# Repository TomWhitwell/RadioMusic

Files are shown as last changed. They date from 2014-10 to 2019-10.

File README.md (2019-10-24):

## Radio Music



### A virtual radio module for Eurorack
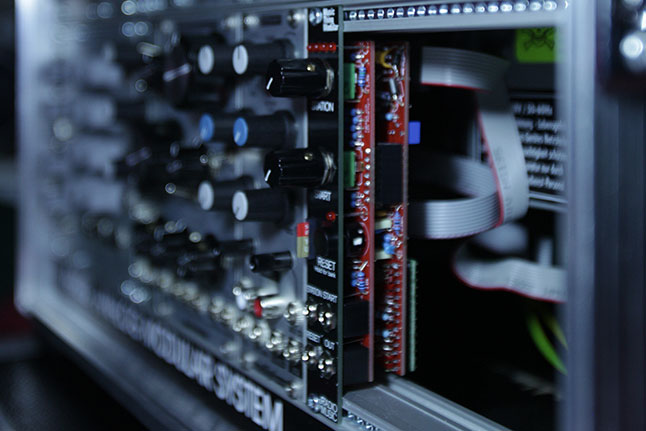
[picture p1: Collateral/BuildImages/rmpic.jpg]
Image from matcsat, Muffwiggler forum


- [Full Documentation](https://github.com/TomWhitwell/RadioMusic/wiki)
    - [Module manual](https://github.com/TomWhitwell/RadioMusic/wiki/How-to-use-the-Radio-Music-module)  
    - [Build documents](https://github.com/TomWhitwell/RadioMusic/wiki/Building-the-Radio-Music-module)  
    - [Setting up the SD Card](https://github.com/TomWhitwell/RadioMusic/wiki/SD-Card%3A-Format-%26-File-Structure)  
    - [Suggested sound library](https://github.com/TomWhitwell/RadioMusic/wiki/Audio-for-the-SD-Card)  
- [Hardware: Eagle CAD files](https://github.com/TomWhitwell/RadioMusic/tree/master/RadioMusicHardware)
- [Hardware: Parts List](https://github.com/TomWhitwell/RadioMusic/wiki/BOM---Parts-List)
- [Firmware: Teensyduino files](https://github.com/TomWhitwell/RadioMusic/tree/master/RadioMusic)
- [Report Issues with hardware or firmware](https://github.com/TomWhitwell/RadioMusic/issues)

This is not a radio. It is a sample player that behaves like a radio.  

A digital way to simulate the radio-powered compositions of John Cage and Karlheinz Stockhausen as well as Don Buchla's voltage-controlled radio experiments. It uses a [Teensy 3.1/3.2](https://www.pjrc.com/teensy/) to play files from an SD card to simulate a voltage controlled AM/FM/Shortwave/Time Travel radio. 

#### Progress  

May 2016
- Merged Jouni's latest changes into the main branch
- New Beta versions in the Collateral/Hex Files folder: Crossfade and a new Bank Change interface
- If you're developing firmware yourself, make sure you read the 'Edited Teensy Files' section, because this has changed significantly

March 2016  
- Updated firmware Beta produced by Jouni Stenroos, fixing several long-term issues including file count limit, hot swapping and resets.  

February 2015  
- [Thonk kits shipping](http://www.thonk.co.uk/product-category/music-thing-modular/)  
- Module being used by:  
    - [Robin Rimbaud (Scanner)](https://twitter.com/robinrimbaud/status/562663428830289921)   
    - [Chris Carter](https://twitter.com/chris_carter_/status/562889299621076993)  
    - [Russell Haswell](https://twitter.com/russellhaswell/status/552213743363690496)  
    - [Richard Devine](https://instagram.com/p/900BnMjQjw/)  
- [Big collection of video and audio demos](http://musicthing.co.uk/modular/?p=1087)  

January 2015  
- Rev2 PCB Files confirmed good  

December 2014  
- [Rev2 PCB files](https://github.com/TomWhitwell/RadioMusic/tree/master/RadioMusicHardware/Gerbers/Rev%202%20Gerbers%20Dec%202014) published, prototyping in process  

November 2014  
- First PCB build   
- [Video 1](http://instagram.com/p/vCNc37DmSj/)  
- [Video 2](http://instagram.com/p/vnv1T-DmUm/)  
- [Longer demo video](http://vimeo.com/113050279)  
- [Audio: Long demo](https://soundcloud.com/musicthing/radio-music-20-minutes-of-madness)  
- [Audio: Random Drums](https://soundcloud.com/musicthing/radio-music-random-drums)  
- [Audio: Random Voices](https://soundcloud.com/musicthing/radio-music-random-voices)   

October 2014   
- Very early prototyping     

#### Features
- 4hp x 40mm deep  
- On-board 5v regulator, does not need a 5v rail.
- 75ma Current Draw   
    - 60ma from 5v regulator  
    - 8ma from -12v  
- Up to 32gb storage, 16 banks of 75 channels each  
- Files stored as headerless .raw wav files
- Customise the module by editing settings.txt on the SD Card

EarlyPanelDesign

#### License  
Radio Music is Open Hardware  
All hardware and software design in this project is Creative Commons licensed by Tom Whitwell: [CC-BY-SA: Attribution / ShareAlike](https://creativecommons.org/licenses/by-sa/3.0/)  
If you use any work in this project, you should credit me, and you must republish any changes you make under the same license.   
This license does permit commercial use of these designs, but consider getting in touch before selling anything.  
This project includes work from the [Teensy](https://www.pjrc.com/teensy/) project, which is not covered by this license. The suggested audio content is not covered by this license.

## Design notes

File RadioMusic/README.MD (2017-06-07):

Radio Music New Firmware

Extra files are no longer needed

To build this firmware and upload to your Radio Music

1. Install Arduino IDE : https://www.arduino.cc/en/Main/Software
2. Install Teensyduino : https://www.pjrc.com/teensy/td_download.html
3. Get a copy of the source code : https://github.com/Normalised/RadioMusic/archive/master.zip
4. Unzip the source code somewhere
5. Connect the Radio Music to your computer via USB. If you are on OSX or Win 10 you won't need drivers.
5. Open RadioMusic.ino in Arduino IDE
6. Click the upload button : Upload

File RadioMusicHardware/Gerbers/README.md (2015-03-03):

#Gerber File Changelog  

##Rev 2.1  
- This folder only includes Front board files. Back and panel boards unchanged from Rev 2   
- Rev 2.1 Changes   
    - Bigger holes for reset button  
    - Correct revision number on silkscreen (!)  

##Rev 2 
- Boards used for first major production run in January 2015  

##Rev 1 
- Prototype boards with ground error on front board. Do not use. 

##NB These Gerbers may not reflect the latest Eagle updates. For latest version, create your own Gerbers from the eagle files.

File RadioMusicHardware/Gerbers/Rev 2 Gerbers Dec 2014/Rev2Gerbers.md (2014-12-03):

##Rev 2 Gerbers  

These gerbers are prepared to Seeed Studio specs   

Things to check  
- The panel PCB includes a cutout for the SD card - this is marked in the Outline layer (.OUT), and also in the milling layer (.GML)   
- On the panel, ask your PCB house not to put their serial number on top silkscreen (the front of the panel)  

The Eagle archive is here as a snapshot of the Eagle files these PCBs were made from. The main eagle files in the repository are constantly updating

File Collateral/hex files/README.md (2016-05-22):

##Hex File Changelog  
23-3-2016: Rev 2.0 BETA (jstenroos)
    - Fixed hotswap
    - Removed file number limit of ~330. Full 1200 files (16 banks of 75 files each) is now possible.
    - Fine tuned reset. Works properly now after channel change. Also can be set to beginning of the file properly.
    - Added optional alphabetical sort for banks.

27-3-2016: RadioMusic_Beta_2.hex
- Code refactored by Jouni Stenroos  
    - Fixed hotswap, file limit, reset and added sort  
    - [Details here](https://www.muffwiggler.com/forum/viewtopic.php?p=2184098#2184098)  
    - Currently being developed [in this branch](https://github.com/jstenroos/RadioMusic/tree/dev_200).
    - [Direct link to the hex file here](https://raw.githubusercontent.com/TomWhitwell/RadioMusic/master/Collateral/hex%20files/Beta/RadioMusic_Beta_2.hex). Save from the browser and rename .txt into .hex  
    
1-3-2016: RM_Beta_Delay.hex  
- As Rev1.1 with longer startup delay as suggested by mxmxmx to fix startup issues seen by some users.  

3-3-2015: Rev 1.2 BETA 
- Rewritten code around channel / time selection
    - Fewer audio glitches while changing channels 
    - Faster, more responsive 
    - More consistent response to reset triggers 
    - Non-Looping one shot mode should be more useful for drum triggering, removes radio-like channel switching completely in this mode. 
- Please log any bugs and issues in the [Issue Log](https://github.com/TomWhitwell/RadioMusic/issues) using the [Beta 1.2](https://github.com/TomWhitwell/RadioMusic/labels/Beta%201.2) tag.  

11-1-2015: Rev 1.1 
- Looping option  
- Tweaks to make module respond faster  
- Fix glitches after bank changes

28-11-2014: Working Code v1

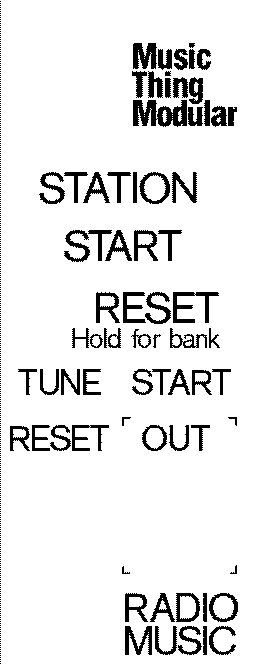
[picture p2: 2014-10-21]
RadioMusicHardware/PanelArtwork/RadioMusic_Artwork.bmp

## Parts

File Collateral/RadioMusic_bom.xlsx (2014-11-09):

Qty | Value | Device | Parts | Mouser Part # | Added | checked
1 |  | 5 x 2 Power Header | SV1 | 649-67997-210HLF (https://uk.mouser.com/Search/ProductDetail.aspx) | y | y
2 | 1N4001 | 1N4001 Diode | D5, D6 | 512-1N4001 (https://uk.mouser.com/Search/ProductDetail.aspx?R=1N4001virtualkey51210000virtualkey512-1N4001) | y | y
1 | 50K | Bourns 3362P Trimmer | Output level | 652-3362P-1-503LF (http://uk.mouser.com/ProductDetail/Bourns/3362P-1-503LF/) | y | y
1 | 78L05 | 78L05 TO92 5v 100ma voltage regulator | IC3 | 512-LM78L05ACZ (http://uk.mouser.com/ProductDetail/Fairchild-Semiconductor/LM78L05ACZ/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) | y | y
2 | 50k Linear | ALPHA 9mm Vertical pots (or 100k) | CHANNEL-POT, TIME-POT | Bitsbox, Smallbear
6 | BAT42 | BAT42 Schottky Diode (or other, or 1N4148) | D1, D2, D3, D4, D7, D8 | 78-BAT42-TAP (http://uk.mouser.com/ProductDetail/Vishay-Semiconductors/BAT42-TAP/) | y | y
2 | BL01RN1A | BL01RN1A Ferrite Bead (or 10R Resistor) | L1, L2 | 81-BL01RN1A1D2B (http://uk.mouser.com/ProductDetail/Murata-Electronics/BL01RN1A1D2B/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) | y | y
2 | 100n | Ceramic Cap | C5, C8 | 594-K104K15X7RF5UH5 (http://uk.mouser.com/ProductDetail/Vishay-BC-Components/K104K15X7RF5UH5/) | y | y
2 | 1n | Ceramic Cap | C1, C4 | 594-K102J15C0GF5TH5 (http://uk.mouser.com/Search/ProductDetail.aspx?qs=uSno%2b7uLFuyBp2%2bv6qsL9w%3d%3d) | y | y
2 | 100n | Poly Box Cap | C2, C3 | 80-R82DC3100AA50J (https://uk.mouser.com/Search/ProductDetail.aspx) | y | y
2 | 10uf | Electrolytic Cap | C6, C7 | Panasonic ECE-A1EKS100 (http://uk.mouser.com/ProductDetail/Panasonic/ECE-A1EKS100/) | y | y
1 |  | C&K D6 SPST Momentary Key Switches | RESET | 611-D6R60F1LFS (http://uk.mouser.com/ProductDetail/CK-Components/D6R60-F1-LFS/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) | y | y
5 |  | 3mm LEDs | LED1, LED2, LED3, LED4, LED5 | 604-WP710A10ID (https://uk.mouser.com/Search/ProductDetail.aspx) | y | y
2 | 40 pins (cut to fit) | 36 Pin Male Header |  | 649-68000-436HLF (https://uk.mouser.com/Search/ProductDetail.aspx) | y | y
2 | 36 pins (cut to fit) | 36 pin Female Header |  | 517-929974-01-36-RK (https://uk.mouser.com/Search/ProductDetail.aspx) | y | y
2 | FUSE | 200ma PTC Poly Fuse | F1, F2 | 652-MFR020-LF (http://uk.mouser.com/ProductDetail/Bourns/MF-R020-0-99/) | y | y
3 | 100k | 1/4W Resistor | R9, R19, R20 | 660-MF1/4LCT52R104G (http://uk.mouser.com/ProductDetail/KOA-Speer/MF1-4LCT52R104G/) | Y | y
1 | 10k | 1/4W Resistor | R8 | 660-MF1/4DCT52A1002F (https://uk.mouser.com/Search/ProductDetail.aspx) | Y | y
1 | 1K | 1/4W Resistor | R7 | 660-MF1/4DCT52R1001F (https://uk.mouser.com/Search/ProductDetail.aspx) | Y | y
5 | 2k | 1/4W Resistor | R11, R12, R13, R14, R15 | 660-MF1/4LCT52R202J (http://uk.mouser.com/ProductDetail/KOA-Speer/MF1-4LCT52R202J/) | Y | y
2 | 200k | 1/4W Resistor | R10, R21 | 660-MF1/4DCVTR2003F (http://uk.mouser.com/ProductDetail/KOA-Speer/MF1-4DCVTR2003F/) | y | y
2 | 220R | 1/4W Resistor | R17, R18 | 660-MF1/4DCT52R2200F | y | y
1 | 330K | 1/4W Resistor | R5 | 660-MF1/4DCT52R3303F | Y | y
2 | 47R | 1/4W Resistor | R1, R2 | 660-MFS1/4DCT52R47R0 (https://uk.mouser.com/Search/ProductDetail.aspx) | Y | y
2 | 8.2k | 1/4W Resistor | R3, R4 | 660-MF1/4DCT52R8201F | Y | y
1 |  | Teensy 3.1 | U1 | pjrc.com, Cool Components or OSHPark
 |  | Pins or stackable long pins for Teensy
1 |  | 14 pin IC Socket |  | 649-DILB14P-223TLF (https://uk.mouser.com/Search/ProductDetail.aspx) | Y | y
1 | TL074 | TL074 Quad Op Amp | IC4 | 595-TL074CN (https://uk.mouser.com/Search/ProductDetail.aspx?R=TL074CNvirtualkey59500000virtualkey595-TL074CN) | Y | y
1 |  | YAMAICHI PJS008U-3000-0 | Vertical SD Card Holder | MSD-HOLDER-3: www.acmesystems.it/catalog_sdcard
4 |  | Thonkiconn Socket |  | Available from Thonk
 | 7 pins | Header Female | JP3 (Back Board)
 | 7 pins | Header Male | JP4
 | 11 pins | Header Female | JP2
 | 11 pins | Header Male | JP1 (Back Board)
 | 14 pins | Header Female | Teensy Socket (Back Board)
 | 13 pins | Header Female | Teensy Socket (Back Board)
 | 2 pins | Header Female | Teensy Socket (Back Board)

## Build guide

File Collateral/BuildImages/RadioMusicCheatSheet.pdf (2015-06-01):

0 ○○○○ Broadcast Radio
1 ●○○○ Unusual Speech & Radio
2 ○●○○ Robotic and Scientific Speech
3 ●●○○ Ambient sounds & Field Recording 4 ○○●○ Melodic and drone sounds
5 ●○●○ Avant-Garde Music
6 ○●●○ Avant-Garde Songs and Poetry
7 ●●●○ Drum Loops
8 ○○○● Hi-fi Test Records
9 ●○○● Music From Earth
10 ○●○● Sounds From Earth
11 ●●○● Nagra Loops
12 ○○●● Gamelan

0 ○○○○ Broadcast Radio 1 ●○○○ Unusual Speech & Radio 2 ○●○○ Robotic and Scientific Speech 3 ●●○○ Ambient sounds & Field Recording 4 ○○●○ Melodic and drone sounds 5 ●○●○ Avant-Garde Music 6 ○●●○ Avant-Garde Songs and Poetry 7 ●●●○ Drum Loops 8 ○○○● Hi-fi Test Records 9 ●○○● Music From Earth 10 ○●○● Sounds From Earth 11 ●●○● Nagra Loops 12 ○○●● Gamelan

0 ○○○○ Broadcast Radio 1 ●○○○ Unusual Speech & Radio 2 ○●○○ Robotic and Scientific Speech 3 ●●○○ Ambient sounds & Field Recording 4 ○○●○ Melodic and drone sounds 5 ●○●○ Avant-Garde Music 6 ○●●○ Avant-Garde Songs and Poetry 7 ●●●○ Drum Loops 8 ○○○● Hi-fi Test Records 9 ●○○● Music From Earth 10 ○●○● Sounds From Earth 11 ●●○● Nagra Loops 12 ○○●● Gamelan

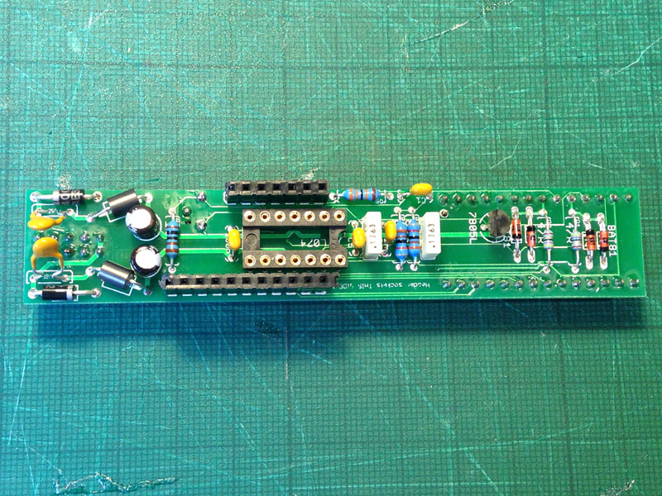
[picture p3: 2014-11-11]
Collateral/BuildImages/08.jpg

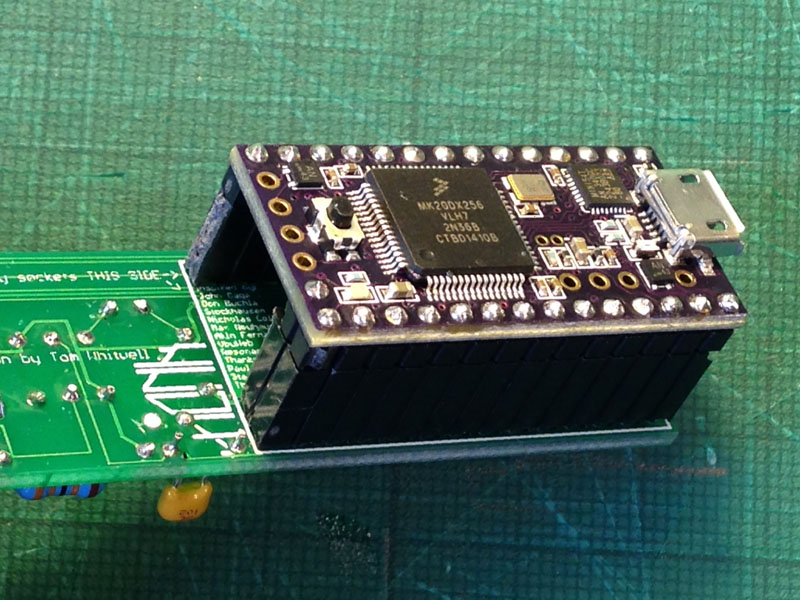
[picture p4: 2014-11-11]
Collateral/BuildImages/15.jpg

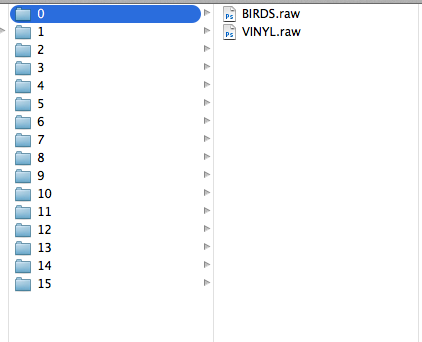
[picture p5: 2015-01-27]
Collateral/BuildImages/FILESTRUCTURE.png

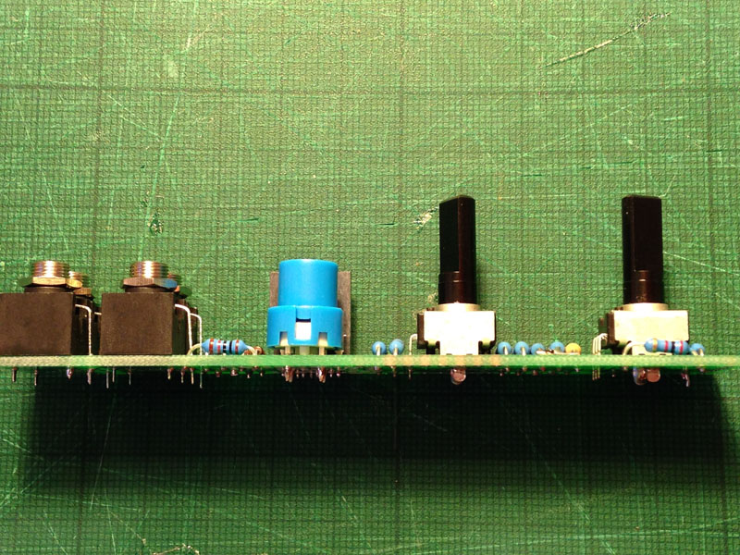
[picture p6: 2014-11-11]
Collateral/BuildImages/41.jpg

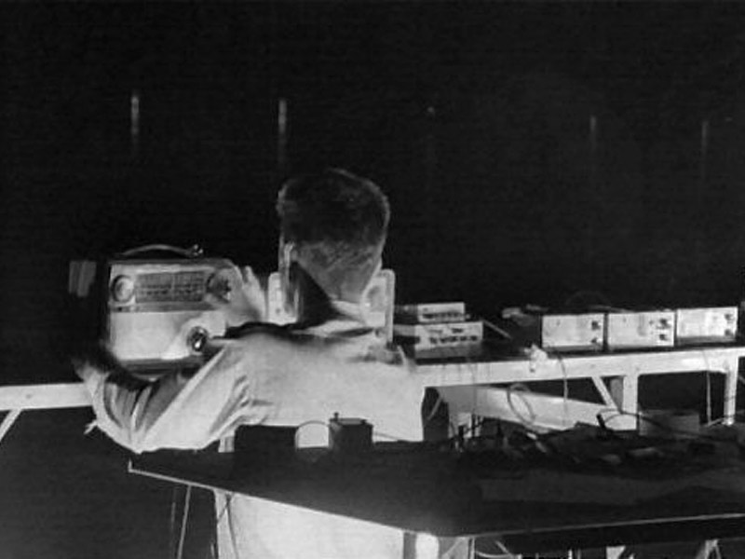
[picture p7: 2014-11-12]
Collateral/BuildImages/cage.jpg

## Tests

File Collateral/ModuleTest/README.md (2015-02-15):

##Module Hardware Test file  

(https://vimeo.com/117123053)  
[CLICK TO WATCH THE VIDEO](https://vimeo.com/117123053)  

ModuleTest.ino is a quick way to check that the hardware in your module is working correctly.  

If you cut the power trace, you'll need both +/-12v ribbon cable power and USB power to upload firmware to the module.  

###Method 1: Basic  
Install the file moduletest.cpp.hex using Teensy Loader in the same way you installed the original firmware ([as explained here](https://github.com/TomWhitwell/RadioMusic/wiki/Preparing-the-Teensy-3.1)) 
You can see lights flashing on the module, it will produce sounds, those sounds will moduluate as you turn the knobs and apply CV. Knobs and CV are also mapped to the 4 LEDs at the top.  

###Method 2: Advanced 
To get feedback from the module and see what's going on, you'll need to install the full [Teensyduino environment](http://www.pjrc.com/teensy/td_download.html). Once that is installed and working (i.e. you can install Blink and see expected results) download and run the [Module Test Sketch](https://github.com/TomWhitwell/RadioMusic/tree/master/Collateral/ModuleTest).  
- You'll see all five LEDs flash in sequence   
- While they're flashing, the module will generate audio - various sine wave tones    
- Once the startup routine is finished, the 4 LEDs are linked to 2xknobs and 2xCV inputs  
- If you run the serial monitor in Arduino, you'll see the knob / CV input values as 0-1024. 
    - Expect to see some jitter from noise - maybe jumping up and down 10 points (these numbers are smoothed by the firmware later on), but you should be able to move each pot from 0 - 1024 smoothly.  

(The alternative firmwares that were in this folder are now documented here:  https://github.com/TomWhitwell/RadioMusic/wiki/Alternative-firmware-for-Radio-Music )

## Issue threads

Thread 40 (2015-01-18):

CV issues

mezzman, 2015-01-18:
I am building a bunch of RadioMusic modules (rev2 PCBs) and I am having odd issues with a few of them. I am seeing the Reset LED and bank indicator LEDs flash while a sample is playing. Sometimes this happens with CV into either Start or Tuner position inputs. Sometimes running audio out direct into an external mixer will cause this (ground loop?), but going into a VCA before the mixer fixes it.
Other times changing voltage going into Start actually triggers reset on voltage change.
And other times just a constant voltage into the tuner position input causes these to flash very rapidly and
audio starts stuttering.
Video of issue: https://vimeo.com/117084179
password: radiomusic

TomWhitwell, 2015-01-18:
I've started a [troubleshooting page in the wiki](https://github.com/TomWhitwell/RadioMusic/wiki/Troubleshooting-the-Radio-Music-module)
And added a few things that might be relevant to you.
Because you're the first - everything on that page is relevant to your questions!

You can get stuttering 'between' stations - either from knob position or from CV input - I haven't yet found any way to avoid that

I'm going to close this issue now, considering it a question answered, but be sure to re-open it if you need more help.

I'll leave issues open once we identify a hardware or software issue that needs to be fixed

mezzman, 2015-01-18:
I ran the test sketch and I am seeing an identical issue across several boards.
What I am seeing is Channel CV and Time CV are noisy with nothing plugged into the jacks. LEDs 3&4 are flickering.
Channel CV ranges from 1 to 280 and Time CV is 1 to 400. Introducing CV into Channel jack makes both LEDs 3&4 change intensity, but only Channel CV changes in value. It still is noisy, as it jumps around 20-30 points. CV into Time jack has no effect on LED 3&4 intensity, but value does change and is also noisy.

TomWhitwell, 2015-01-18:
Hi, take a look at issue #13 re: values for R21 and R10
https://github.com/TomWhitwell/RadioMusic/issues/13

Also, if you have Rev1 boards, there is a ground error:
https://github.com/TomWhitwell/RadioMusic/wiki/PCB-Version-History

See the fix here regarding the legs on R21 and R10:
https://github.com/TomWhitwell/RadioMusic/wiki/Building-the-Radio-Music-module

mezzman, 2015-01-18:
I am using rev2 boards and the following resistor values:
R10 47k
R21 47k
R9 22k
R20 22k
I can try different values, would going lower be a good place to start?

TomWhitwell, 2015-01-18:
Those values work fine with my setup, so I don't think that's the problem.

mezzman, 2015-01-18:
Are you getting individual LED control for each CV input on the test?

TomWhitwell, 2015-01-18:
Hi,
I've updated the test sketch (there was a bug in the LED display, sorry)
And made a demo video to show how it's supposed to work:
https://github.com/TomWhitwell/RadioMusic/tree/master/Collateral/ModuleTest

mezzman, 2015-01-19:
Thank you. I downloaded the updated test sketch and now I am getting a curious issue. On a module that had no apparent noise problems at the CV inputs with the old test sketch now shows noise at the Time CV LED with nothing plugged in there, and goes away with 0v input via external source.
I am measuring -.1v between pin20/A6 and gnd.

TomWhitwell, 2015-01-19:
I sounds a lot like a hardware grounding issue; a bad connection somewhere. The ground path goes all the way through the Teensy itself, so it could be anywhere on the boards.

TomWhitwell, 2015-01-19:
On an unplugged module, put a patch lead into one of the CV inputs, and use a multimeter to check the resistance between tip and sleeve. It should be 47K

mezzman, 2015-01-19:
I am getting around 43k on both CV inputs.

monobass, 2015-01-19:
I'm seeing 47k on both Station and Start.

mezzman, 2015-01-19:
I removed the TL074 and connecting pin 8 on the socket to GND stops the noise. This pretty much rules out bad grounding. I am suspecting the opamp is the culprit, will try to find some locally today and swap it out.

mezzman, 2015-01-19:
I tried a different manufacturer of TL074 and also a TL084 with no improvement. back to square one. I just do not know why this is happening with all boards that I'm having this negative voltage offset which is causing the noise.

mezzman, 2015-01-21:
I am going to do a separate build with PCBs from a different source to test with, I will close this issue now.

monobass, 2015-01-29:
mezzman what value pots did you use?

mezzman, 2015-02-01:
50k linear Alps (from small bear) on both pots. Yes I had grayscale panel installed. I removed panel and there was no difference

Thonk-Steve, 2015-02-01:
Ah I wondered cos I ran into some cv drifting issues when using metal-shafted 100k pots, particularly on the Start pot... And even more so when the panel was off and they weren't grounded. Once I swapped back to 50k and put the panel back on the problems disappeared again.

mezzman, 2015-02-01:
That's interesting. The issues I have had were only on the CV inputs, the pots were rock solid.

Thonk-Steve, 2015-02-01:
Yeah they are rock solid now. I updated the bom to warn people off using 100k pending further testing.

mezzman, 2015-02-01:
I would also say stay away from Itead as a PCB fabricator, I used a PCB made by Seeed and it worked perfectly with no noise issues at the CV inputs. I have also had confirmation from others that Itead has had quality control issues.

Thonk-Steve, 2015-02-01:
Oh yeah iTead are definitely worth swerving! Their boards have been pretty poor for a couple of years now. Seeed protos on average much better from a manufacturing standpoint, the silkscreen on protos is pretty hit and miss. This issue should be closed then?

mezzman, 2015-02-01:
Yes, this issue has been resolved as far as I can tell. Progress has been made.

Closed 2015-02-01.

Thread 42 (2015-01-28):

Nov 2014 Mouser Project

m-akers, 2015-01-28:
In addition to:

      200k Resistors 660-mf1/4dcvtr2003f = strange vertical format, not usable
      Doesn't agree with rev1 PCBs: LED resistors ordered are 2k
      Switches are BLUE!
      47R resistors are weirdly tiny
      Only 1 x 100n ceramic, should be 2

Doesn't account for resistor changes described in "issue 13".

Only 1 x 1nF cap (1000 pF), should be 2.

TomWhitwell, 2015-03-06:
Fixed, thanks to @m-akers

Closed 2015-03-06.

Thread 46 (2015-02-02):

Replacing pots with encoders

Thonk-Steve, 2015-02-02:
With thoughts of how Radio Music could be reprogrammed to be other things, would replacing the pots with rotary encoders require only software changes?

mxmxmx, 2015-02-02:
no.
encoders are wired differently.

Thonk-Steve, 2015-02-02:
I need to read up on encoders :)

Nantonos, 2015-02-02:
Hello Thonk-Steve,

Monday, February 2, 2015, 1:34:55 PM, you wrote:

> I need to read up on encoders :)

Encoders typically use two digital input pins, each one with a train
of pulses. From the phase response of the two, not only the rate of
turning but also the direction can be determined.

http://en.wikipedia.org/wiki/Rotary_encoder#Incremental_rotary_encoder

There is an Encoder library which can be used on teensy.
http://www.pjrc.com/teensy/td_libs_Encoder.html

But the PCB layout for an encoder and a pot are different. A pot is
typically connected to some constant voltage and to GND, with the
variable voltage on the wiper being read by an analog input.

--
Best regards,
 Nantonos                            mailto:nantonos@epona.net

mxmxmx, 2015-02-02:
short story short: it wouldn't involve very drastic changes, just rerouting a few traces. but then encoders are kind of pointless without some kind of display (?)

Thonk-Steve, 2015-02-02:
There's a push button and 4 leds up the top, with an encoder you could have 4 different modes quite simply

Thonk-Steve, 2015-02-02:
or obviously you could do a latching kind of thing with a pot... but I was never so keen on that.

TomWhitwell, 2015-02-03:
Going to close this in the interests of tidiness!

Closed 2015-02-03.

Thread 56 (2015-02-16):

Strange behavior : flickering reset LED + stutter sound

Onosendaifr, 2015-02-16:
Hi,

Strange things begin to happend after 1 day of perfect working, and it seems to happend when the sound is stronger than a very little treshold :

Reset LED begin to flicker and the sound stutter like a time streching effect (the sound continue to play but advance by grain as is the sound was, at high speed, stopped, then starting point moved a little bit further, then play resume). At this point reset button have eratic effect, don't really reset the sound.

I can't understand why, i've tried to reset the setup file without success. Any help ?

Thonk-Steve, 2015-02-16:
Do you mean this was a problem with a specific .raw file or part of a file?

Onosendaifr, 2015-02-16:
No, it happend with every files (i use you library).

It's very strange, because it seems to be trigerred by the volume of a sound, very quiet sound are played normaly, this behavior start when the level pass a certain amount.

The playback is ok when the module is "cold" and just booted the modular, but 3 or 4 minutes later, it begins.

Could be a bad soldering joint, maybe near the reset/start/station, i will double chack that.

Thonk-Steve, 2015-02-16:
If you power off your case then power on again once it happens.. does it still happen immediately? If so then if you power off, leave for 30 mins then power on again is it happening then? That might help rule out any temperature fluctuations that are expanding/contracting a cold solder somewhere.

The other thing to test is whether it happens when nothing else is plugged into the power supply, could you perhaps be near the limit of your power supply current? Radio Music does draw more power than your average 4hp module.

Onosendaifr, 2015-02-16:
> That might help rule out any temperature fluctuations that are expanding/contracting a cold solder somewhere.

It seems to be the case ! I will inspect than thanks.

TomWhitwell, 2015-02-19:
You could also check to see if this looks like some of the issues referenced in #55 re glitches while slowly moving the station knob - however, if you have sound stopping, that sounds very different

mezzman, 2015-02-19:
I have had the same issue and believe this is related to issue #54
I believe there is a voltage offset present at the start CV which is causing the issue.
Onosendaifr, can you run the module test sketch and see if you have any LEDs lit without any CV inputs?

Onosendaifr, 2015-02-19:
What is the test sketch ?

I've inspected all the solder joint and correct the ugliest one, all my problems seem to be gone \o/
I will wait one or two days like this to see if it's ok, but as Steve find it, the reason was certainly a cold solder.

BUT

I also have the #55 issue :) Wich is a completly different problem i think

Do we need to wait for a firmware update about this one ?

TomWhitwell, 2015-02-19:
@Onosendaifr That's great news. I'll close this thread now, reopen if it comes back.

#55 will be a firmware update, no ETA on that.

Closed 2015-02-19.

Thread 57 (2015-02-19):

Enlarge PCB holes for switches

TomWhitwell, 2015-02-19:
According to datasheet, button pins should be 0.5mm x 0.8mm

Drill holes on the PCB are 0.81mm - these should be enlarged to .95 or 1mm

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

TomWhitwell, 2015-02-19:
Fixed on Eagle files - haven't updated the Gerbers

Closed 2015-02-19.

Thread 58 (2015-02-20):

Resistor Fix on rev 1 boards

Thonk-Steve, 2015-02-20:
regarding this section of the build doc

* If you are using a Rev1 board, fix the grounding problem on R21 and R10 by soldering their legs to R13 at the 'super careful' end. This is already fixed on the red PCBs from Thonk.

Actually while this is indeed fixed on the red Thonk Front PCBs, I just realised they actually do say rev 1 still (the back PCB correctly says rev 2)

Other than that R21 and R10 ground trace fix on front pcb rev 1, are there other easy ways to identify which board you have if you don't know the source of them Tom?

TomWhitwell, 2015-02-20:
OH, how annoying.

Yes:

- New, updated boards have curved traces, old Rev1 boards have straight traces
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

- New, updated boards have 1.5k LED resistors (like R11), old Rev1 boards have 1k LED resistors
- You can see the fix in place on the new boards - R21, R13, R10 all connected to ground:
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

I'll create an issue to fix the Rev. Number

Thonk-Steve, 2015-02-20:
Ah nice one cheers Tom

Closed 2015-02-25.

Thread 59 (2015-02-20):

Fix revision number on Front boards

TomWhitwell, 2015-02-20:

Closed 2015-02-25.

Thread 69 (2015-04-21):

RM doesn't work

zonkt, 2015-04-21:
Hello, after some e-mail exchange with Steve at Thonk. This one asked me to post my problem here.
 When I connect it on the busboard nothing happens,
No red lights that comes on, only the orange led on the teensy on the back is flashing.
The teensy is well recognized when I connect it on the computer using the teensy software.
I start to mount the module with the teensy before install the firmeware.
I well check all my solders and everything seems to be clean.
I wonder if i get a right tennsy. Any ideas.?
If it's can help i have severals photos that steve asked me to send.
Thanks in advance.
all the best.
laurent

TomWhitwell, 2015-04-21:
"only the orange led on the teensy on the back is flashing" almost certainly means the Radio Music firmware is not installed.
Check:
https://github.com/TomWhitwell/RadioMusic/wiki/Preparing-the-Teensy-3.1
https://www.pjrc.com/teensy/troubleshoot.html

Closing this now - please reopen if you still have a problem

zonkt, 2015-04-23:
Hi Tom,

Thanks for your reply.

I mount the module before installed firmware.

But didn’t soldered directly the teensy on the module

But on the female pin sockets.

So, after finished to mount the module, I installed firmware

In removing the teensy from the sockets and made it in connected

Directly the teensy on the usb computer.

So, I installed firmware, but should I do it in using my modular power

And cut up the USB power trace?

Thanks for your reply.

All the best.

laurent

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

jamescarruthers, 2015-04-23:
If you cut the USB trace then you need to power the Teensy via the module — so connect the USB whilst it's in your rack and powered up.

zonkt, 2015-04-23:
Yes, it’s what i understood. But like I already installed firmware and made it again several times in seeing the module not working,

My question is do you think I should use this way to have my teensy and module working?

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

jamescarruthers, 2015-04-23:
I am not sure I totally understand.

Yes, you should cut the power trace as per the instructions.

Yes, you should load the firmware on to the Teensy whilst it's powered by the rack.

zonkt, 2015-04-24:
Oh sorry !

I just wonder that since I have not soldered directly the  teensy on the  module, and therefore I can remove it from its base, why should I do the firmware by connecting the module with the teensy on my system and not remove it from the module and connect it directly on the computer through the USB socket. I hope i'm a little clearer.

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

jamescarruthers, 2015-04-24:
Because it won't work unless it's in the module - because you cut the trace.

zonkt, 2015-04-24:
No, i didn’t cut the trace……Not yet!

It’s why I ask before doing it!

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

TomWhitwell, 2015-04-24:
OK, if you didn't cut the trace, just connect the teensy to your computer and upload the firmware.

You only need to the cut the trace if you will ever want to have computer + modular power AT THE SAME TIME (i.e. because you are debugging the module or writing code).

zonkt, 2015-04-24:
Ok, it’s well what i understood !

I already upload the firmware….may be 10 times!

This one seems to be ok, it’s why I don’t understand it’s not working!

I can send you photos I made for steve if it’s can help!

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

TomWhitwell, 2015-04-24:
If the LED on the Teensy PCB is flashing, then you haven't installed the Radio Music firmware, you have installed the test 'blink' firmware.

zonkt, 2015-04-24:
Here is what i use to install.

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

zonkt, 2015-04-27:
Hi Tom,

Yesterday, I reinstalled for the thirtieth time at least teensy firmware, I installed it in my system and grrrrrr !!! I realize I have plugged it in backwards !! First time it happens to me. I turned, and taken off my hot radio music, I reconnected to the place! Ouff not grilled but still my two LEDs that flash back. I disconnected, I reload the firmware by pressing reboot, something I had also done many times! I reconnected in my system, and it works ...... red LEDs that light up front for the first time. When module’s world starts flirting with metaphysics, do not try to understand! J

Thanks for your help!

All the best.

laurent

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

Thonk-Steve, 2015-04-27:
Hi Laurent,

Glad it's working! Do you mean you plugged in the power cable backwards or the teensy?

Regards

Steve

zonkt, 2015-04-27:
Hi Steve,

Thanks !

I plugged the power cable backwards !

It seems that the radio music loved that!

All the best.

laurent

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

Thonk-Steve, 2015-04-27:
Ah well that's a good test of the reverse power protection :)

Closed 2015-04-21.

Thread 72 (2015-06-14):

Loud hiss on the output comes and goes

gorasou, 2015-06-14:
Hi

I have a really weird issue with my Radio Music. There is a really loud noise on the output that's even louder than the files themself. thing is that it's gone sometimes, giving me a perfectly clean signal. I really don't know what the problem could be or what to do as I'm not a experienced diy-er. it worked fine for a couple days until there was hiss for the first time. and now sometimes it's there, sometimes not...

I hope someone can help out, thank you in advance.

Marc

TomWhitwell, 2015-06-14:
Hi!

Please read #50 and see if it is same problem.

If it is definitely hiss (ie high frequency white noise) and not hum (ie 50/60hz buzzing) then please record the effect and upload a link here.

gorasou, 2015-06-14:
It's not the same problem unfortunately, I already tried that :(

here's an example for the noise. it worked a couple hours ago but now it's back on...

https://www.dropbox.com/s/gqzuvhagbebstu0/Radio%20Music%20Noise%20Probelm.wav?dl=0

TomWhitwell, 2015-06-14:
Thanks, I haven't heard that sort of problem from anyone before, particularly if it is intermittent.

It sounds like a high-pitched hum, different from the mains hum that some people experience when working across cases, and different from the noise that a few people have experienced when adding very quiet samples.

And - it is inconsistent, so unlikely to be a simple hardware problem within the actual module.

Not sure what to advise, you could try:
- checking all of the connections on the board
- trying to understand what causes it to come and go
    - Do you have other bits of equipment that are sometimes plugged in?
    - Lighting, or cooling or other electrical noise-generating devices nearby?

michaelhaeusler, 2015-06-24:
Hi,

I am having the same problem. It is the same hum and clicking sound but it is much louder compared to the sound from the SD-Card. The humming is always there . When the SD-Card is removed it changes it's frequencies (1 octave higher) und and is shortly interrupted periodically (every two seconds).

I checked the module with the module hardware test and everything works fine and no noise is present but as soon as I install the RadioMusic Firmware (v1.1) the humming is there again.

@gorasou Did you find a solution for the problem?

Thonk-Steve, 2015-06-25:
michaelhaeusler is this definitely the same problem do you think if your noise is not intermittant as gorasou reported? Does it sound identical to the soundclip that gorasou supplied?

michaelhaeusler, 2015-06-25:
Yes, only that the noise is louder compared to the sound. Apart from that the hum sound is exactly like the soundclip from gorasou only that I have an additional periodical clicking sound and it is always there. I can provide a soundclip this evening.

Thonk-Steve, 2015-06-25:
I'll admit I'm baffled too as I've never come across one like this. gorasou and michaelhaeusler, it's probably worth posting photos of both sides of both PCBs.

michaelhaeusler, 2015-06-25:
I'll will provide some photos tomorrow. Here are the noises - the first with an SD card the second without:

https://dl.dropboxusercontent.com/u/3398946/radio_music_noise.mp3
https://dl.dropboxusercontent.com/u/3398946/radio_music_noise_without_card.mp3

michaelhaeusler, 2015-08-16:
So I finally made it to make some photos of the PCBs. Unfortunately the problem still exists. I double checked all soldering but the noise is still there. As I said there is no noise when doing the module hardware test so it might have something to do with the card reader?

Here are the photos:
https://dl.dropboxusercontent.com/u/3398946/IMG_2371.JPG
https://dl.dropboxusercontent.com/u/3398946/IMG_2372.JPG
https://dl.dropboxusercontent.com/u/3398946/IMG_2373.JPG
https://dl.dropboxusercontent.com/u/3398946/IMG_2374.JPG

breedx2, 2015-08-16:
One of the yellow capacitors next to the power bus header looks like it's poorly soldered from the top of the board, and from the bottom I can't even tell what's going on there -- looks like a gashed open hole.  Fortunately, it looks like the traces are just on the top...

I would definitely touch that up with some solder from the top and then do a continuity check to make sure it's going where you think it should be going.

TomWhitwell, 2015-09-20:
Closing after inactivity

michaelhaeusler, 2015-12-18:
Sorry for my very late reply. I had re-checked all solderings back then as breedx2 had suggested and made the continuity check but without success. The loud noise is still there which makes the module unusable. I had given up after that because I had no idea how to continue. Is there anything else I can do? Is it maybe possible that one component isn't working correctly? As I mentioned the noise is not there when doing the module hardware test. So maybe the SD-Card reader is somehow faulty? I am grateful for any kind of help!

djamsia, 2016-02-04:
I recently set up a Radio station.
there is no silence when no sounds, there is always a ground noise.
also get a loud hum from the reset input. when it used as an output.
I have the pcb rev2.1

Closed 2015-09-20.

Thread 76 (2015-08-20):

Fried my teensy

Lektroid, 2015-08-20:
I just managed to drop my radio module down the back of the modular while it was powered up, the two PCBs separated and it burned out the teensy. I've ordered another, but want to make sure the voltages are correct going to the teensy before frying a second one... With the common probe of the meter grounded (to one of the leads of the input diodes), I get these results on the 78L05:
Input: -12V
GND: -9V
Output: 4.75V

So between Gnd & Output on the Vreg, there is a difference of -5V

The output looks ok when referenced with the common ground, but seems a bit strange that I'm getting -9V at the Ground point of the Vreg, I would have assumed it shared a common ground? Can someone let me know if these voltages are correct?

I'll swap out the Vreg and see if it looks more normal...

Lektroid, 2015-08-20:
tried a new Vreg, same (or very similar) results. I have no teensy board fitted at this point (just checking everything is normal before the risk of frying another).

I noticed a strange voltage reading to the teensy when I probe common to Teensy Ground point, I'm getting -5V where there should be +5V...?

Going from the other end of the PCB, I've checked voltages from the power connector to the opamp inputs, all checks out as it should.

Lektroid, 2015-08-20:
*facepalm* I had the probes backwards in my meter

TomWhitwell, 2015-08-20:
Have a look here re: testing the power supply voltages: https://github.com/TomWhitwell/RadioMusic/wiki/Testing-and-calibrating-the-Radio-Music-module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

Closed 2015-09-20.

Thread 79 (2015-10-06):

everything (might) work, except no audio out.

taylor12k, 2015-10-06:
i just built my 4th radio music. the previous 3 all went smoothly, it's not difficult. but on this one i'm not getting any audio out.

there appears to be normal activity on the LEDs and with CV input. i say "appears" because all i can do is go by visual activity... without being able to hear anything i can't tell for sure.

because i have 3 other working modules i've tried all of their SD cards in the new one, swapped cards around, etc... so i know it's not the card or formatting.

i've reflashed the firmware a couple of time and that seems to go fine.

when i first plugged the module into my case it was causing a weird power short ... so i took it out and realized i had a solder bridge.. once i cleared that up the power was fine.. but i'm hoping that didn't fry anything on the module. but, again, because LED activity seems to be "normal"... i don't think so.

any ideas?

TomWhitwell, 2015-10-06:
Things to try:

Check the output pin from the Teensy - you need two rows of pins down each side, then another at the end - that's the DAC output, so if it's missing, it would behave as you describe, and it's the kind of mistake I'd make.

https://github.com/TomWhitwell/RadioMusic/wiki/Building-the-Radio-Music-module#mounting-the-teensy

It's possible but unlikely that you could have fried the TL074 op amp - swap that with one another module and see if it makes a difference

taylor12k, 2015-10-06:
i swapped the op amp with a different radio music and it still doesn't work... but the other one i swapped it with does, so it's not the op amp.

the DAC pin is there...

TomWhitwell, 2015-10-06:
If you have other modules, you can swap the front and back boards with another - see if that isolates the problem - i.e. if the back board on your new module works on another, you know the problem is on the front board of the new module. (Hope that makes sense... )

Thonk-Steve, 2015-10-06:
was about to say exactly that :)

taylor12k, 2015-10-06:
good idea... will try that now

taylor12k, 2015-10-06:
yes, putting the back board from the un-working module onto a working one makes it not work.. so the problem lies in the back board.

Thonk-Steve, 2015-10-06:
Also swapping the teensy out? You need to test all three elements
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

taylor12k, 2015-10-06:
yeah, not looking forward to un-soldering two teensys..... nope!

Thonk-Steve, 2015-10-06:
ahhh... didn't realise you soldered them.

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

taylor12k, 2015-10-06:
hmmm.. time to throw in the towel?

TomWhitwell, 2015-10-06:
Assuming the Teensy is running code (as the LEDs suggest) the issue must be here:
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
or here:
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

Have you checked the trimmer is turned up?
Checked the pins on the output socket?
Have you remembered to solder R17 into place on the front board?

taylor12k, 2015-10-06:
hi tom,

yes, have moved the trimmer back and forth...

output pin seems AOK

don't see any missing resistor spots on the boards.. R17 looks good

Thonk-Steve, 2015-10-06:
Probably time to throw some photos up for your own sanity :)

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

taylor12k, 2015-10-06:
but then you'll see how atrocious my soldering skills are :)

taylor12k, 2015-10-06:
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

taylor12k, 2015-10-07:
did i scare you off with the photos? :)

TomWhitwell, 2015-10-07:
Gosh, when I look at photos like this I just think 'ouch, I could have routed that better'

It all looks neat and correct to me - I think @Thonk-Steve has slightly more experience of photo debugging than me.

We can't see the back of the TL074 - but unless there's something really obvious (unsoldered pins) I don't know what that would be.
Unfortunately, the only RM I have at the moment is an earlier prototype - Russell Haswell stole my other working one.

jamescarruthers, 2015-10-07:
It's like cobblers children

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

taylor12k, 2015-10-07:
the back of the TL074 looks ok to me, no unsoldered pins or anything....
hmmm...

unless steve sees anything... might be time to find another one.

Closed 2015-10-29.

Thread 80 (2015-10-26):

Blown teensy, no 3.3v line? Please help

adh82, 2015-10-26:
Hi,
I built the radio kit and all looks fine.
Before I plugged it in I was getting correct readings from the calibration instructions. I had it up and running then it just stopped, teensy got real hot.
Module is dead and it fried my  SD. Now when I plug the teensy into the computer via USB it gets really hot quickly but doesn't register with the app.
But after I spoke to STEVE from thonk about it he asked to check the 3.3v line and I'm not getting it.
Maybe around 0.12v? I still have correct voltages when checked via calibration instruction, but these don't mention anything about 3.3v.
Will I only see these when the teensy is installed?
Would anyone know what the problem is?
Where to track the 3.3v source?
Do I need all boards connected and jumpered?
I want to get to the bottom of it before I install a new teensy.
Don't want another to die on me.

Cheers,

Adrien.

TomWhitwell, 2015-10-29:
Hi, sorry to hear that,
Here are the instructions about testing the power supply circuit before you install the Teensy.
https://github.com/TomWhitwell/RadioMusic/wiki/Testing-and-calibrating-the-Radio-Music-module

adh82, 2015-10-31:
Hi Tom,
So I've checked the voltages with your instructions and all is fine.
I do get about + and - 12.10v
And 5.10v
I guess this is due to my power supply. Is that ok?
Glad to hear the teensy outputs the 3.3v.
So in theory if I install a new teensy all should be ok regarding the voltages in getting?

Regards,
Adrien Harris

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

TomWhitwell, 2015-10-31:
Hi Adrien, yes - those voltages sound correct - don't worry about the 0.10v! Should be OK.
Check your soldering when you added the pins to the Teensy - any shorts there could cause problems, or any nudging of the tiny components on the teensy itself

Closed 2015-10-31.

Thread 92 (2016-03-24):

Reset CV input not working?

jamesbernard, 2016-03-24:
The module is working perfectly otherwise, Reset button works. But no matter what signal I send to the Reset CV input.. it never resets. I tried a number of different sources (MN Function, Doepfer A-160/161, Pulse clock).. no luck.

Any clues?

TomWhitwell, 2016-03-24:
Reset input is normally very reliable - it's a passive connection to the board via a couple of resistors.
So - it can only be a soldering / component issue.
On Front board (with pots @ sockets)
Check r19 and r18 are what they should be
Check d7 and d8 are the right way around
Check inter-board connecting pins are all soldered
Check all teensy pins are soldered correctly
Check the reset jack is soldered correctly

That's all it can be, really - probably either a missing component (r18 absent or swapped with a higher value would do it) or a short to ground somewhere

jamesbernard, 2016-03-25:
Checked all solder points and did not find any issues or ground loops. What finally worked was removing the 220R (R18) and placing a jumper in it's place.

Closed 2016-03-25.

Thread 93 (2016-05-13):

Resetting continuously by itself

Setherian, 2016-05-13:
I just finished my module, started testing and the reset function is being activated by itself continuously in a unrecognizable pattern (random?) (led blinks accordingly), its a very fast process and I dont know how fast it should be in terms of actual sound response but in the end I either get a recognizable reset or "clicks".
What to do?

TomWhitwell, 2016-05-13:
If it resets regularly every 400ms, then you have probably soldered the button 90 degrees off where it should be - so it looks electrically like it's constantly pushed down.

If the resetting is much more random/faster than that, it might possibly be a grounding issue - try the module in a different case, patch a few other cables into the module.

Reopen this case if neither of these sounds useful.

Setherian, 2016-05-13:
Hi Tom, after extended testing, the self reset frequency varies, but usually it takes a few seconds to appear and sometimes it can not happen at all for a long time, but the random burst of clicks continue and very frequently so, they seem to clearly relate to the "above reset LED" blinking, I think you are right about ground , while the behaviour didn't changed when I switched cases, it changed a bit, only for a while though when I sent the output straight to my audio interface, instead of going to other modules. SO yeah for a few seconds it seemed like the blinking n clicking was way less regular but still happening sometimes but now even in that config, straight to computer I get frequent blinks n clicks.
But I have no idea how to deal with this grounding if that is indeed the problem, what do you suggest?

Closed 2016-05-13.

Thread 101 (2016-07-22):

Hi Friends,

SynDrum, 2016-07-22:
Problem with Radio Music, maybe FW, maybe SD Card settings

SynDrum, 2016-07-22:
Hi,
 I have the following problem(s) with my Radio Music Module. At first, when i pluged it in the first time, I just got the four top LED's flashing, maybe every half second, when i pulled out the SD Card, I had the of you discribed "4 lights flash together, and after a few more, you'll hear a thump at the module output as it goes into a slow cycle of auto reboots.". When i was wondering, whats wrong, I installed the hardwear-Check via Arduino, everything turned out to be fine, works as it should. Then, I wanted to reinstall the Radio_Musix.hex firmwear, which seems to work but now,  I neither have any sound-result, or the 4 lights flashing together, as it goes into the cycle of auto reboots. Any suggestions, what I should do know? The only thing thats on, is the Reset LED, and i have a little "one shot" sound when i pull out the SD Card,

Cheers, and thanks in Advance,

Niclas Helbig

TomWhitwell, 2016-07-23:
Hi, sorry to hear that. Things to check:
What is on the SD card? Ensure it is known good, as here: https://github.com/TomWhitwell/RadioMusic/wiki/SD-Card:-Format-&-File-Structure

Is it a reputable brand SD Card

Check soldering on the tiny pins on the SD Card holder

SynDrum, 2016-07-23:
Hi,
Yeah, I'll try that.
The brand should not be a prpblem, its a 16gb SanDisk, but i only formated it with my Smartephone, since I don't have a Micro-SD reader
Do you think the issue, with the firmwear thats not loading correctly anymore, has something to do with the circumstance, that i didnt cut the power supply? I read its "kind of" nessesary if you troubleshoot. Does it cause any serious damage to the teensy if i havent done so yet? :)

TomWhitwell, 2016-07-23:
You definitely need to load the SD Card properly.

Re: cutting the trace & troubleshooting, it's quite simple, doesn't matter which you choose:

If you CUT the trace, you need to supply 12v power from the ribbon cable AND USB power - this means you can run the module properly while it is connected to the computer.

If you DO NOT CUT the trace, you an use 12v ribbon power OR USB power. So you can reprogram the Teensy just by connecting with USB cable, but you can't troubleshoot with the module active in your case.

Either one works fine long term in the case.

TomWhitwell, 2016-12-12:
Closed because no response

Closed 2016-12-12.

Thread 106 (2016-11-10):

pulsing buzzy sound plays through other modules even when not patched

jbook808, 2016-11-10:
Hi Tom, I recently assembled a DIY radio music kit and everything is great except there seems to be cross talk / interference traveling from the RM to other modules in my system.

I've exhausted all troubleshooting skills I currently have and would greatly appreciate your help tracking down the issue.

Here is what I know:
• the sound is buzzy, almost like a pulsing square wave (maybe  clock signal coming from RM?)

• the sound loops with audio playing from the SD card.
     • The sound does not play if audio is not playing, ie. with RM in one shot mode, pulse goes away when audio file finishes playback
     • removing SD card removes issue

• the sound glitches out and seems to restart rapidly as Channel Pot is moved

• reset button resets pulse loop

• the sound travels from RM to headphone out of Beface Output II module, but not main output.

• the sound can be heard in the system when RM output is left unpatched
     • sound disappears if RM is removed from PSU

• the sound can be heard in the output section of Befaco BF22 filter when plugged into the same system.

• If the RM is loaded with test .hex files, the issue goes away. The issue is only present in RadioMusic1_1.cpp.hex, and RM_crossfade_2.0b3.hex.

• I am using a Tip Top Audio uZues PSU
     • I've tried RM with a pittsburgh PSU and issue persisted

• I tested and found no continuity between +12v and GND... -12v and GND... or +12v and -12v

• I feel like the issue is grounding related. If I plug a stereo headphone jack into the RM out, I hear the pulse, which makes me think the pulse must be coming through the sleeve of the stereo headphone jack?

I took some pictures of the PCBs to show soldering.

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

Thanks in advance for your help! I plan to upload audio examples tonight when I get home from work.

Best,
j

TomWhitwell, 2016-11-10:
Hi, sorry to hear that - what PSU are you using?

jbook808, 2016-11-10:
Hi!

I’m using a tip top audio PSU. I also tested with a pittsburgh PSU with same results.

Best,
Josh

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

jbook808, 2016-11-10:
Sorry for the double email. Tip Top Audio uZeus.

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

TomWhitwell, 2016-11-11:
uZeus can be tricky for grounding issues because of the cable busboards - that said I've used my uZeus to demo Radio Music at events very successfully. I can't see anything obvious - looks like a nice tidy build.
I'm not really sure what to suggest - it's not an issue that I've heard elsewhere - it does sound like a symptom of grounding issues in the system. If you connect more sockets to the Radio Music (i.e. into reset or the CV inputs) does that have any effect on the noise (the patch cables act as another path to ground)

jbook808, 2016-11-11:
Below I've uploaded a few audio examples. There is a lot of hiss, but that's from other modules.

RM is in one shot mode in all examples to show interference is present only when audio is playing back.

RM Interference 1.mp3 - Mono output of system with no patches made. Interference is triggered by reset button 2 times and then the station knob is turned. Station knob triggers reset button and illuminates reset LED.

RM Interference 2.mp3 - RM Output patched into output module L. The interference is greatly amplified and makes sample playback unusable.

RM Interference 3.mp3 - Patch into station from filter out, station modulates extremely fast and squelches.

RM Interference 4.mp3 - trigger input  going in to 'STATION'. This example shows station cv creates squelches as well as triggers reset button.

[RM Interference Audio Examples.zip](https://github.com/TomWhitwell/RadioMusic/files/586543/RM.Interference.Audio.Examples.zip)

bscooper, 2016-11-17:
I finished my radio today, and all functions works nice. But i have also some rhythm sounds like "tac tac tac tac". Always, unimportant if a sound plays or not. It is like laying down a cell phone near then radio. I know that thismis something with the grounding in the power supply and in the connection between different modules. but why is the radio the bad guy? Which electronical part in the radio could be the problem? perhaps there is a way to fix with a better high quality part?

jbook808, 2016-11-17:
not sure! were you able to download the audio examples i uploaded above? does this noise sound like the noise you are experiencing?

Tom, do you think something like the Synthrotek Noise Filtering Power Distrobution Board might help with this issue?

NickShaffner, 2017-06-16:
whats that extra resistor you've got wired on the back of the bottom board?

I'm having much the same issue and am trying to track it down.   Did you ever find a resolution for this?

Building the think 2.1 full kit, I've gone over the pcb a few times and only found one of the signal diodes reversed which I replaced with a 4148 (docs say it's ok to do so).    I beeped through the board and got the scope out.   Looks like a 'reasonable' audio signal on the teensy dac pin which mimics the led  u meter.   However by the time the signal reaches the header pin between the front and rear it looks just like noise.

Using a Pittsburg modular supply and no other modules (this is my first eurorack module :) )

Will sleep on it and get the scope out again tomorrow.   It does feel a lot like a weird grounding issue.

Will do some more scoping tomorrow, but this

jbook808, 2017-06-20:
The extra resistor is a fix I found somewhere in the forums for an issue where noise quality would start to degrade after about 15 minutes of use. I added it in hopes that it would fix the noise that leaks between modules. No luck, though.

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

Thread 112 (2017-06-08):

Sounds distorted. No pitch over samples. Sample doesn't play without reset trigger

Normalised, 2017-06-08:
From this thread : https://www.muffwiggler.com/forum/viewtopic.php?p=2573666#2573666

so i trued a couple of codes from polyfather without success ,

i install the official release as well,without great luck as well,
now sounds distorted and no pitch over samples, also i have to trigger the sample now from the reset in in order to be played, i remember that wasnt the case when i got that thing to work first time.

Normalised, 2017-06-08:
I'll need all the details to work this out.

1. Exactly which hex file you used
2. The contents of settings.txt
3. The layout of the SD card folders and the contents
4. The brand and size of the SD card

pflab, 2017-06-08:
1.Exactly which hex file you used:

[Radio_Music_2017.1.zip](https://github.com/TomWhitwell/RadioMusic/files/1060911/Radio_Music_2017.1.zip)

2.The contents of settings.txt
i do not know what you mean by this one, sorry, happy to upload sth if you explain, do you wont me to open the code and upload the txt?sorry i have no clue from digital devices

3.The layout of the SD card folders and the contents
Layout of SD cards, in both modules , are files from 0-15 , inside every folder .wav files randomly named

4.The brand and size of the SD card
SanDisk Ultra 16 GB MicroSDHC UHS-I

Normalised, 2017-06-08:
The 'settings.txt' is a file that is on the SD card which controls how the module behaves.

If you haven't downloaded one from the http://polyfather.com/radio_music/ application then there will be a default one on the SD card.
You can open this file in a text editor, e.g. notepad and copy and paste the contents in a comment here.

If you wish to try the 'pitch mode' then you need to turn on the option on the web page above, click 'download configuration' and copy the downloaded settings.txt to the SD card.

Thonk-Steve, 2017-06-08:
pflab on "sounds distorted"

maybe you knocked the trimmer on the back of the module by accident when upgrading software? try trimming that whilst playing sound to see if the distortion goes.

pflab, 2017-06-08:
ok

normalised, i will upload the settings,txt later today
i also think i was having the pitch mode on, but i was downloading and flashing the . hex files inly, never copied anything at the SD card, so it might be that.

steven , i ll have a look at the volume pot in case there is gain related from that

i will spend few hours after work
thanks for the great support

pflab, 2017-06-08:
ok
normalised.
settings txt.

crossfade=0
crossfadeTime=25
showMeter=1
meterHide=2000
chanPotImmediate=1
chanCVImmediate=1
startPotImmediate=0
startCVImmediate=0
startCVDivider=2
looping=0
sort=1
pitchMode=0

pflab, 2017-06-08:
so

i have news,

i made a new scenario at polyfather ,
downloaded the .hex but this time the settings.txt.
flashed the hex
copy pasted the NEW settings txt

and all is up and working now

Thonk-Steve, 2017-06-08:
Interesting, are you in Windows or OSX?

pflab, 2017-06-08:
though ,
is the sampler supposed to be played everytime a cv(here is pitch mode) is at start input,
because at the moment I always have to trigger it from reset.
Or I have to make some choices at polyfather to choose that as an option, sorry if a have been annoying

thanks very much

pflab, 2017-06-08:
steven,

I am using Windows

Thonk-Steve, 2017-06-08:
How did you copy the new config over? Just drag it to the SD card in the
file explorer? As there any issue with the file not being writable or card
not being writable or did it just work?

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

pflab, 2017-06-08:
just delete the old settings.txt from the SD that was from the old script ;
and copy-paste the fresh ones
and it just worked

Normalised, 2017-06-08:
For the 'change start cv to retrigger sample' you have to change this :

startCVImmediate=0

to

startCVImmediate=1

Which on the polyfather app is the 'Start CV Immediate' option.

And no, you're not annoying. We're here to help as best we can :)

pflab, 2017-06-08:
lovely lovely,

one of my summer aims is to learn some coding

all the best, and thanks to everyone that got involved on this project

petros

pflab, 2017-06-12:
guys still i can not get start iput to retrigger the sampler together with pitch
any ideas:

crossfade=1
crossfadeTime=50
showMeter=1
chanPotImmediate=1
chanCVImmediate=1
startPotImmediate=1
startCVImmediate=1
looping=0
anyAudioFiles=1
pitchMode=1
hardSwap=1
quantizeRootPot=0
quantizeRootCV=1
startCVDivider=1

Normalised, 2017-06-13:
But the button does retrigger?

What signal are you sending to the start input?

pflab, 2017-06-13:
Yes the button does retrigger, changing samples, I will check when I will be at home for sure.

I have tried with few different signals digital s&h and sequencers to try to get v/Oct and retrigger

pflab, 2017-06-13:
yeap, i can verify that the button,
re-triggers and changing samples when pressed and input signal in reset,
when cv in start will change pitch , but nth is happening unleash there is a signal in reset

thanks

Thonk-Steve, 2017-06-13:
pflab could you record a quick video showing what you mean?

pflab, 2017-06-13:
good idea steve

https://youtu.be/TuSSReiOjX4

pflab, 2017-06-15:
/any news on this one, how does it looks to you ? ok ? i am start think i am doing sth wrong during the programming process

Normalised, 2017-06-16:
I'll look into it more this weekend.

pflab, 2017-06-17:
Normalised, you can have  a wee look but I am not gonna have Access to my synth for the next two weeks, so I won't be able to feedback with any more details for now. Thanks for all the help

Normalised, 2017-08-31:
First thing, I can see you have 2 RM modules, is it the same on both?

pflab, 2017-08-31:
yes, that is correct, both modules respond in the same way, one more sign i am doing sth wrong at the flashing script i guess

Normalised, 2017-09-10:
Ok, I think this all just a misunderstanding. I thought you were talking about the RESET input not retriggering the sample in pitch mode, but you're saying that you expect the START input to retrigger the sample in pitch mode. But in pitch mode the start input has no effect on start, its purely a pitch control AND changing the pitch DOES NOT retrigger the sample.

If you want to change it to also retrigger the sample you'll have to build the code yourself, the relevant parts are here :

https://github.com/TomWhitwell/RadioMusic/blob/069d035f33ae1ed93387e639efec3417c8bd05ba/RadioMusic/RadioMusic.ino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

pflab, 2017-09-10:
ok, and sorry for the misunderstanding
thanks for all your patience, and support,
thanks for a great project

Normalised, 2017-09-10:
No problem. Sorry it doesn't work like you expected, hopefully we'll be able to add this as an option in future, something like pitchCVRetrigger=1.

Closed 2017-09-10.

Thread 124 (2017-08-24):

Wave Form button not working, Wave Form randomly changing when moving dials

kokodrimpy, 2017-08-24:
Hi,

I assembled the kit and it was working in perfect shape.
Until today :_(
By mistake I put a CV signal into the output, then I tried the module and the Wave Form button is not working, also the Wave Form randomly  s changing when moving the chord and root dials.

There is sound coming out of the module and it is coherent with the waveform displayed in the LEDs.

Please help!

Bests,
Pablo

kokodrimpy, 2017-08-24:
Here it is a video of the current module behaviour

https://youtu.be/zbxVYSthG4U

actually it seems to be an issue with the trig input....

TomWhitwell, 2017-08-24:
Hi Pablo,

Trig is an output - it pulses when chord changes, so you can trigger an envelope generator or whatever.
Not sure what would happen if you put a signal into that - should be nothing, and it won't damage the module (in Radio Music, it's an input), but not sure what would happen.
If you don't plug anything into trig, does it work normally?

Tom

kokodrimpy, 2017-08-25:
Hi Tom,

Thanks a lot for your quick response. If nothing is connected to trig it behaves the same way.

There is nothing connected to trig at the beginning of the video https://www.youtube.com/watch?v=zbxVYSthG4U&feature=youtu.be
Still, I get the wave forms changing randomly.
I've just reformatted the teensy but I behaves the same.

Pablo

kokodrimpy, 2017-09-05:
Hi Tom,

Well, I tried everything I could think off. Formatted the SIM card, checked for cold soldering (didn't found any but still did some re-soldering in some points). I tested the button and it works properly.

The only thing that i comes to my mind is either a controller or IC failure. Do you think this is more a TL074CN problem or an Teensy one?
Remember that all this seems to start happening after I put a CV signal into de audio output.
Is there any test that you would recommend to check for failures?

Please help!!! I was really loving my chord organ :_(

Bests,
Pablo.

oblivionratula, 2017-09-05:
That video is a trip because it's mirror-flipped. ;)

I'm no expert, but the TL074 is socketed and cheap as chips, so I'd definitely try swapping that first. I'm inclined to think, looking at the schematics, if you killed the DAC with the voltage, you'd not be getting any sound now. On the other hand, if the OpAmp didn't like the voltage, I could see where messing up channel A or D might have strange effects on how channel B or C is feeding voltage to the Teensy.

But again, I'm no expert.

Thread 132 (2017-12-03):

Problems compiling and uploading new firmware

MegaGlabrous, 2017-12-03:
I am attempting to update my radiomusic (which has been working perfectly for 18 months or so with the original firmware) to the latest. I downloaded Arduino 1.85 and Teensyduino with no apparent problems. But I am failing to Verify or Upload the new code.

Can anyone help?
Verify fails with:
[Verify.txt](https://github.com/TomWhitwell/RadioMusic/files/1524781/Verify.txt)

Upload fails with:
[Upload.txt](https://github.com/TomWhitwell/RadioMusic/files/1524782/Upload.txt)

TomWhitwell, 2017-12-03:
Hi, you don't have to compile anything to use the new firmware, just upload the .hex file with teensy loader. Tom

tomterrien, 2019-01-31:
Hi Tom , i'm Tom :)
I'm trying to update radio Music's Firmware with the sampler one but teensy app says "unreadable" when i open the .hex file :/

Thonk-Steve, 2019-01-31:
Are you grabbing the firmware from here?
http://www.polyfather.com/radio_music/

'DOWNLOAD FIRMWARE' at the top of the page

Cheers

Steve
Thonk

On Thu, Jan 31, 2019 at 11:13 AM tomterrien <notifications@github.com>
wrote:

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

tomterrien, 2019-01-31:
Maybe i'm not in the right topic ? :)

TomWhitwell, 2019-01-31:
You might be having trouble downloading the .hex file from github

Try this link: https://raw.githubusercontent.com/jamescarruthers/RadioMusicAltFirmware/master/Sampler_1_0.hex
- then 'save as' and save as text
- then edit the file so it's called sampler_1_0.hex (remove any .txt extension)
- Open the .hex file in a text editor - if you see a series of numbers after colons, that's correct.  If you see HTML code, that's not correct

Upload that using the Teensy Loader app, NOT the Arduino IDE

tomterrien, 2019-02-02:
Found solution ! sorry for the late reply, i downloaded it zipped and it's fine , update done. Now i have to figure out ouut to be creative with this ^^
Thanks !

Tigersi76, 2020-05-02:
I'm late to the party and very much a newbie, can anyone help.

I'm looking to update my Radio Music to the 2017 firmware.
Do i have to have the module connected to my system whilst uploading or can i just take it out of the rack and upload it with my mac via usb?

Thank you so much for reading this and sorry if this seems like a dumb question to most of you.

Si

eeweegh, 2020-05-02:
it depends on whether the USB power trace on the teensy has been cut or not. You can find all of the info on https://github.com/TomWhitwell/RadioMusic/wiki/Preparing-the-Teensy

Tigersi76, 2020-05-03:
@eeweegh
Thank you so much for your reply. I have read through that and already had but am still unsure.
I feel daft for asking these questions as it’s probably simple stuff to you guys.
Here are the pics of mine. I think there is no connection but would appreciate for someone who knows to confirm.
Once again thank you for your time.

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

eeweegh, 2020-05-03:
I think there *is* a connection, and you can just power it up and upgrade it, connecting it solely to USB. Look at your second picture, bottom right of the Teensy: there are three pads (a big one (VUSB) and two smaller ones). As far as I can judge, there is still a trace (thin copper line) between the two small pads.
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

Tigersi76, 2020-05-03:
Once again thank you so much. @MegaGlabrous this has sorted it.
I now have .wav on my module.
Very very much appreciated

Si. :)

scheersvincent, 2021-02-06:
Hi!
im also having issues switching between chord organ firmware and radio music, i want to switch back to radio music firmware.

when i attach the module with a usb cable to my macbook, the red light above the "station" know lights up, so i dont think the powerstrip was cut.
However the LED on the teensy is never lighting up

When i try to upload the firmware via the teensy loader, the program doesnt seem to respond,

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

scheersvincent, 2021-02-06:
Also pressing the button on the teensy doesnt change anything

scheersvincent, 2021-02-06:
Pressing the physical button on the teensy only makes the red light above the "station" know stop lighting up

TomWhitwell, 2021-02-06:
Hi @scheersvincent there are a lot of tips here:
https://www.pjrc.com/teensy/troubleshoot.html

I don't know if it's just the image you used, but that screenshot shows "blink_slow_TeensyLC.hex" - the file you need is "blink_slow_Teensy32.hex" because you're using a Teensy 3.1 or 3.2 (the same brain)

Tom

scheersvincent, 2021-02-07:
Hi Tom,

Thanks for taking an interest, i appreciate it!

After everything i tried the chord organ mode still works fine in my case, which i think indicates that there is nothing wrong with the teensy itself. its just uploading new firmware where im stuck at.

Im hoping the issue is just that my usb-cable isnt made for data transfer but just for charging, i ordered a proper one and will keep you posted.

Cheers,
Vincent

scheersvincent, 2021-02-09:
Fixed!

Just had to use a proper usb cable, now installing new firmware works like a charm!

thanks @TomWhitwell !

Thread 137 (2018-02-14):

Teensy not connecting

dedwen13, 2018-02-14:
Hey!
I recently got my hands on a second hand Music Thing Radio Music and for some strange reason teensy app doesn't find the teensy chip after pressing the program mode button.

I had it set up in the rack before trying to program it and it seemed to work. I downloaded a firmware (Radio_Music_2017.2.hex) which seems to be too large for the chip as well. program and reboot mode are inactive.
I'm using a mac with OS 10.9.5.
After calling the seller who was all nervous on the phone he told me that there needs to be some sort of bridge between some solder points which I believe is absolute bullshit.
any chance to reset the teensy chip in another way to get the latest firmware and the module working again?
best regards,

dedwen

BBGuy, 2018-02-14:
Hi  dedwen13
The seller is corect. Checkout the section "Cut the USB power trace" on https://github.com/TomWhitwell/RadioMusic/wiki/Preparing-the-Teensy

Thonk-Steve, 2018-02-14:
have more faith ;)

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

dedwen13, 2018-02-14:
@Thonk-Steve hard if you got ripped couple of times but as you see I still try my best :)

TomWhitwell, 2018-02-14:
Always nice to have a happy ending

Closed 2018-02-14.

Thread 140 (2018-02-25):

Lights Blinking in Fast Succession when inserting SD card

electrojoeuk, 2018-02-25:
Module powers up fine (I think...). First LED comes on, then after 3 seconds it moves through each LED (i.e. 1, 2, 3, 4). However, as soon as I put an SD card in (I've used the Blank template file 0-15), the LEDs blink in fast succession, and a clicking sound is produced, but no SD card sounds. I'm thinking this might have something to do with the SD card holder? Hex file seems to have loaded fine... Anyone had and SOLVED a similar problem?

Going mad....

electrojoeuk, 2018-03-02:
So I tried re-soldering the card slot and touching up the solder in general, tried multiple brands of SD cards,  still same issue. However, I decided to load the Organ Hex file and its works great, although I didn't test the SD card feature. So as far as I can tell it must be something to do with the circuit path when reading the SD card...

Thonk-Steve, 2018-03-02:
Hey electrojoeuk, could you post good photos of both sides of both PCBs please?

electrojoeuk, 2018-03-03:
Hello Steve, as attached. Many thanks.
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

eeweegh, 2018-03-04:
just my 2c, I'd reflow a few of the components, so you get a nice solder bump at the component side. Not sure it's going to cure your problem, but at least you wouldn't have to worry about unreliable connections.

Also (and now in pedantic mode, so bear with me), give the board a good scrub with IPA to get the flux residue off: it looks nicer :-), but it helps you to better see a bad solder connection or a bridge.

electrojoeuk, 2018-07-27:
Was so fed up with debugging, decided to build a new one from scratch... Same problem. All the microSD cards I had been using were Class 10, decided to try a Class 4 microSD, worked like a charm!

Thonk-Steve, 2018-07-27:
What brand were the class 10 cards?

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

electrojoeuk, 2018-07-28:
The ones I couldn't get to work were the following:
SanDisk Extreme - 32GB - Class 10
Integral - 16GB - Class 10
Team - 8GB - Class 10

Thonk-Steve, 2018-07-28:
Yeah I'm stumped, I've only ever used SanDisk class 10 cards since radio
music was released. Let us know if you run into any more problems.

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

francescoco, 2019-03-18:
@electrojoeuk
what's the green resistor on the back of the pcb for ?

simonjuha, 2019-03-18:
> @electrojoeuk
> what's the green resistor on the back of the pcb for ?
https://github.com/TomWhitwell/RadioMusic/issues/70

Closed 2018-07-27.

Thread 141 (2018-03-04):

Faint / noisy output and weird channel / time cv readings

o55k, 2018-03-04:
Finished building the module yesterday and I am experiencing some weird behavior and I was wondering if anyone could give me some pointers on further troubleshooting.

Starting out with the radio music firmware the only output sound i was getting was a buzzing noise, after switching to the chord organ firmware i was getting very faint output but mostly drowned out by the same buzzing noise.

When testing with the diagnostics firmware I noticed that the readings for channel and time CV inputs seem strange, this is with nothing connected to the inputs:

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

Turning the pots changes corresponding values as expected.

Connecting an LFO to the inputs slightly affected the readings but in what seemed to be a mostly random fashion.

Everything else seems to be working as expected, the output still has a bit of a buzz but much less compared to other firmwares.

Things I have tried:
 - I have inspected the boards to the best of my ability and I am unable to find any solder bridges or misplaced components, also checked all the connections on the teensy and they seem fine.

- Touched up some solder points that may have needed a bit more solder.

- Implemented the distortion fix as described in issue 70.

I have made one odd observation however, when measuring R19 with a multimeter I get a reading of 70k, will try to replace it as soon as I have time.

I will also try and replace the TL074 as well as testing with another Teensy as I have some on the way for other projects.

Here are pictures of the boards, since taking them I have improved the soldering on R1.

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

o55k, 2018-03-07:
Just thought I should give an update on this. Turns out the problem was never with the module itself. I used my brand new case and power supply for testing and it turns out that the power supply was defective. I realized this after putting this project aside and installing a module I knew was in working order in the new case.

Closed 2018-03-07.

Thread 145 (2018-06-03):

Digital noise drowns the audio

simonjuha, 2018-06-03:
When i power up my RM i get some werid digital noise which drown the original audio, as soon as anything gets plugged into it. The noise stays even when unplugging the inputs.
The noise seems to disapear for at short time when i touch pins on the teensy with my finger.

I have checked all the solder joints and even resoldered som that seems worthy.

Thonk-Steve, 2018-06-03:
Hey, some questions:

Is it operating normally other than the noise?

What other modules are in the case? Anything with a lot of LEDS or a screen?

What power supply are you using?

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

simonjuha, 2018-06-03:
I have build two RM. The one of them works perfectly, the other one is the one with the problem. So i doubt it is something with the case or other modules.

I am using the doepfer A-100 diy kit.
No modules with screen or many leds.

also i tried switching the Teensy between the two modules.

Thonk-Steve, 2018-06-03:
Hi Simon, you've identified that  problem is solely down to the teensy then
when you swap then? The main modules have identical performance?

If not I'd suggest also trying combinations of the main two PCBs too.

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

simonjuha, 2018-06-03:
both modules are having the digital noise problem.
The noise comes when somthing in plugged into a input.
The noise remains even after turning on and off the whole rack.
The noise disapear when rack has been off for some time.

I soon have a new case finished. Will try to use the RM-modules in the new one, and see if the noise remain. Thinking it actually might be the case somehow.

simonjuha, 2018-06-03:
UPDATE:
I tried putting the RM-modules into another case; digital noise still acts the same way as before.
Tried putting the ouput from the modules into another mixer; same.

Thonk-Steve, 2018-06-03:
Yeah thats interesting.. it's a Doepfer PSU2 with the 'donut' toroidal
transformer?

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

simonjuha, 2018-06-03:
No. it's a AC to DC and a external 15v ac adatper.
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

I think i said that the noise disapear when i touch Teensy. It's actually seems to be pin 5 or something on the Tl074.

simonjuha, 2018-06-20:
Tried with SD-card rated class 10 instead of class 4. Noise are the same.

simonjuha, 2018-06-20:
Okay. i might have fixed the whole thing. having a 330k from pin 12 on the op amp to ground seems to keep the sneeky noise away :) would there be some other problems with doing this?

Closed 2018-06-21.

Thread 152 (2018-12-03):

Reset trigger "pops" Audio Output

hankyates, 2018-12-03:
Hi there,

For whatever reason it sounds like DC is leaking into the audio output from the reset. Any advice for trouble shooting this?

I suspect that maybe there is a capacitor or diode somewhere that isn't doing it's job, but I am unsure of which component.

hankyates, 2018-12-31:
Did some more investigation last night. I resoldered all capacitors which did not fix the popping. I noticed that the popping seems to be get louder as the audio signal from the DAC gets louder. Leading me to think this might be a software issue. I tried setting the "declick" setting but this didn't resolve the issue either.

Thonk-Steve, 2018-12-31:
Hi Hank,

Can you upload a direct recording of how this click sounds?

Thanks

Steve
Thonk

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

christophebruynseels, 2019-04-17:
Hi,
I am having the same problem. Whenever i reset the sample it clicks in and out. I tried to attenuate the cv but that didn t help, also tried different settings in the software but nothing seems to help.

chris

Thonk-Steve, 2019-04-17:
Hi Chris, same request as for Hank then, it's best if you can upload some
recordings. Also do you have an oscilloscope? It would be useful to check
you don't have a DC offset in your system which is a common cause of clicks.

On Wed, 17 Apr 2019, 16:24 christophebruynseels, <notifications@github.com>
wrote:

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

hankyates, 2019-04-23:
Hey Steve I'll get you some audio but I did check with an oscilloscope
couldn't find any DC leaking. It's pretty strange because it doesn't appear
in the audio peak waveforms either.

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

mercurialization, 2020-06-09:
Has this issue ever been acknowledged/corrected? I'm having the same issue as well on a brand new build. I've set the crossfade as high as 1000ms in hopes of stopping the click/pop, but it doesn't affect the sound when 'Reset' is triggered. It makes the module a bit unusable for my case which is ambience.

hankyates, 2020-06-10:
@mercurialization could you post an audio sample?

jacoblysgaard, 2020-10-27:
I have the same problem. Here is an audio recording where it should be quite pronounced.

https://soundcloud.com/lysgaardsounds/radiomusic-clicks/s-tfgHjwRkvpf

gogoha, 2020-11-03:
Same problem, i have tried with two quality SD cards

klendroid, 2020-11-27:
Having this exact issue as well. Here's a recording:
https://soundcloud.com/user-292410369/radiomusicnoise

Did you guys figure it out?

jacoblysgaard, 2020-11-27:
We did not!😭

klendroid, 2020-11-28:
Bummer! I have to say, I get the distortion all the time though, not just when pressing reset. It's always there.

klendroid, 2020-11-28:
I tried a different SD-card now, and tried to load in only the default RAW-files from the 8GB pack thing found here:
https://github.com/TomWhitwell/RadioMusic/wiki/Audio-for-the-SD-Card

... and now it works just fine! No distortion or glitching. :)

jacoblysgaard, 2020-12-09:
I tried just this, but even with the stock .raw files, I still get the same pops. Weird.

Morbo78, 2021-01-08:
I have the same problem and I'm using Sandisk and Kingston 32GB cards. It seems to be a bit better with the trigger input rather than the button, but it's still there. Tried altering crossfade settings, reinstalling the firmware and settings file, reflowing solder joints...

I'm using a Befaco PowSkiff power supply, but it also does it when just connected to my FC Power, too.

Links to audio files and photos of the boards here: https://drive.google.com/drive/folders/1TVoPL_2BiNpGv0wWosxHMdvPfK_WrFkP?usp=sharing

gogoha, 2021-08-16:
After format the card (Kingston 16Gb HC I U1 Class10) with "SD card formatter" app (overwrite format) and put the default RAW-files (uncompress directly on the sd card!!) that's work (2 hours testing).

MrMojoRisinGottaKeepOnRisin, 2023-11-06:
Getting a loud Pop/Click sound every time the **RESET** button is pressed and every time a signal is sent to the **RESET CV** jack. Using firmware version _"Radio_Music_2017.2.hex"_. Tried reformatting high quality microSD cards and also generic no brand name microSD cards. Tried several variations of the _"settings.txt"_ file but had the same results on three different RM modules. Reverted back to the old firmware _"RadioMusicA2.hex"_ and the Pop/Click sound is not present. Using older firmware is not a good solution for me because I would like to use all of the new features available with the latest version _"Radio_Music_2017.2.hex"_

An mp3 file containing four samples with Pop/Click examples is here -->
[**_http://llamamusic.com/docs/Radio_Music_Pop_and_Click_Problems.mp3_**](http://llamamusic.com/docs/Radio_Music_Pop_and_Click_Problems.mp3)

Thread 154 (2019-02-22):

Station/Reset CV sometimes selects wrong file

starmandeluxe, 2019-02-22:
I have two Radio Music modules (Rev 2.1 boards, latest 2017_2 firmware, loaded with WAV files) and both have this same issue: inputting a stepped CV (e.g. Turing machine or sequencer) into the Station CV jack does indeed change the channel, but sometimes it gets "confused" or "stuck" and fails to switch to the next channel and just plays the previous channel again, or just decides to play a completely random channel instead. Immediate is off for Channel CV so it waits for a trigger signal, which I clock to send at the same time as the Channel CV sequence.

Basically, trying to sequence some sample changes consistently is impossible. I tried reducing the number of files in one bank from 16 down to 8 and finally down to 4, but the issue still happens even with just 4 files.

My Teensy version is 3.2 and my trigger CV has been tested with: Erica Synths Pico Trigger, Sputnik 5-step voltage Source Pulse OUT (variable pulse width, tried various widths).  I recorded a demonstration of these working correctly with a Pico Drum but the same CVs not consistently working correctly on both Radio Music modules:

[https://www.youtube.com/watch?v=yohYsuVO__o](https://www.youtube.com/watch?v=yohYsuVO__o)

Thonk-Steve, 2019-02-22:
Hi Alex,

A few questions:
What version of the firmware do you have loaded?
Did you build them yourself?
Where did you buy them?

Thanks

Steve

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

starmandeluxe, 2019-02-23:
Hello! These are from Thonk, firmware is the 2017_2 latest one I pulled from polyfather a couple of days ago.

Actually it looks like I was able to solve the problem via simply the settings file via this forum post suggestion:

`chanPotImmediate=1
chanCVImmediate=1
startPotImmediate=0
startCVImmediate=0 `

I have no idea why this fixes the issue but all is well now. I'd be curious to know the logic behind it though.

starmandeluxe, 2019-02-23:
OK I did some more testing and think I understand why it sort of solves the problem. These settings do not rely on the Reset trigger CV at all. It changes the station when the CV changes. I am not sure why that would be more accurate than waiting for a Reset trigger. It seems the combination of the reset and the station CV isn't working completely. My guess still leans on the reset circuit path having some issue. I'll try doing some basic troubleshooting with those related parts.

Basically it is usable for triggering at the same rate as the CV change (constant change). One hacky workaround would be to make a "silent" track at the start to simulate "don't play on this beat".

starmandeluxe, 2019-03-02:
I essentially fixed this issue by modding the firmware. I added an updated hex file into my branch here ("RadioMusicResetCVFix.hex"):

https://github.com/starmandeluxe/RadioMusic/tree/patch-reset-cv/Collat eral/hex%20files/Beta

Basically I just wait for a FALLING signal to trigger the reset so that it waits long enough to catch the station CV change.

Details here: https://www.muffwiggler.com/forum/viewtopic.php?p=3018268#3018268

It's not a perfect fix, but I'll close this issue since the module is now usable enough for me. Thanks!

Closed 2019-03-02.

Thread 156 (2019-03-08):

High pitched noise on output

jcrbcn, 2019-03-08:
I can hear the sound file playing, but there's always a high pitch noise over the actual sound.

Here are two examples of the noises over the bird sounds from the "Blank" pack:

1. https://www.dropbox.com/s/c7f2eibqlica260/Radio%20Music%20Audio%20Out.aif
2. https://www.dropbox.com/s/kom5buqeoz7pxjh/Music%20Thing%20Audio%20Out%202.aif

LEDs, CV, reset button and pots work as expected. The audio doesn't. Tried it plugging CV, output through HEX MIX VCA... Also checked the components and current.

I assume that there are some issues related to mine, but I still haven't found a clear answer to this.

Thanks

starmandeluxe, 2019-03-11:
Good timing that you posted this issue, since I've been having this problem for a while (since I built my Radio Music), but just started looking into it and [posted this thread](https://www.muffwiggler.com/forum/viewtopic.php?p=3023551) about it. Some others have reported this problem on the main build thread as well.

My issue is not as extreme as yours (which firmware are you using?) but the underlying problem may be the same. Also, how do you prepare your samples? Try normalizing to maximize the amplitude of your audio files. Also play around with the gain trimmer on the back of the module.

I haven't found a solution for this one yet (I don't think anyone has), but there are some steps you can take to get it to at least a usable state.

jcrbcn, 2019-03-27:
I've been using the 2017 v2 firmware. The samples I used were the ones from the "Empty SD Card" pack, so I assumed no normalization or bit depth change had to be done.

And yes, in pitch mode the knob changes the buzzing noise frequency.

elterotero, 2019-03-27:
I have seen the same issue also recently, did some reflowing, making sure the hardware was as it should be and after almost losing hope reformatted the Sd and copied the files back. It worked for a few days without the noise but now I can see that the noise is coming back again.

Latest firmware and V2 board.

Sent from my iPhone

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

starmandeluxe, 2019-03-29:
> And yes, in pitch mode the knob changes the buzzing noise frequency.

That's interesting. The reason I asked is because it does the same for mine as well (try with a silent audio file). If that is the case, wouldn't it stand to reason that the buzz is introduced in the software, not the hardware? Although I don't know the full signal path, it is suspicious. Sorry I can't give more help, right now I have my module on low gain on the trimmer to minimize it, but I'm not sure it will help you with such an extreme case. Maybe also try the steps that @elterotero suggests.

Thonk-Steve, 2019-03-29:
The implementation of pitch on the Radio Music was very much pushing the
hardware in a direction quite far away from the original concept Tom
settled on with Radio Music, which was literally to fill the module with
lots of long form 'Radio like' audio that is constantly playing, and the
concept of tuning between those 'channels'.

So the pitch mode is certainly a bonus feature and it does reveal that this
module doesn't have a super low noise floor.

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

PZHRHG, 2019-05-13:
Ciao .. I use ADIO MUSIC mostly as DRUM Machine . I always have as FIRST FILE with 1sec of SILENCE. (sort=1) . first File is 00_SILENCE1SEC
that help me to switch between the BANKS real time while playing without having first file to fire audio and also allow some Chocke tecniques that I liked a lot on my DinkyTaiko.  I don't use PITCH Shift.

I also have a very audible High Pitch digital noise . and using Silnece file a lot it is very audible.
It is also very audible when I use Sines

This is very bad because so far to mask the issue I'm foced to play mostly Noise Samples (Haswell like)
but for more clean programs I might need to migrate to another module (like Tiptop ONE) , I really hope not.

Is there any improvement in the pipeline ? is this issue possible to solve ?

thology, 2019-08-08:
Having this exact same issue. Identical to your problem of that high pitched noise. Almost like a ground loop. Have there been any fixes for this?

Eliad-beep, 2020-04-30:
Hi all,
I am experiencing the same issue as well. The background buzz is not as loud as the examples posted here but still loud enough to grab attention and disturb music. I almost lost hope with this one and am considering selling my RM (although I am having lots of fun with it). are there any new discoveries regarding this?

niall-munnelly, 2020-06-28:
+1 here, too.
There is a low red noise rumble when the module is idle, and a droning done with audible ticks during sample playback. The higher-pitched noise lasts as long as the sample plays and cuts abruptly when playback ceases. I’m using a modified firmware, but the behavior is the same.

Thonk-Steve, 2020-06-28:
If you want to upload audio samples of the noise we'd be happy to listen
and compare to what we know the noise of a normal radio music sounds like.
The ideal sound would start with a 0db tone, then have some silence and
then end with another tone.

Like all Eurorack modules you should experiment with where it is in your
case (far away from PSU is a good idea) and also keep it away from very
electrically noisy modules (worse culprits are modules with screens,
expensive 'conputer' modules and l
Those with lots of LEDs).

Also if you are using a switching type PSU, the cheap laptop type ones can
be very noisy. It's best to work out other strategies first though.

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

adamjav, 2020-09-04:
Hello all,
I recently went through a similar issue. In my case it was absolutely a soldering problem on the back PCB with a capacitor in the audio path close to the DAC output. The soldering looked fine on inspection but the component was loose. I found it by recklessly "feeling around" the board while powered and outputting audio. Putting my finger in a certain spot would make it work normally. I powered it off, added a bit more solder. All good since then. Just wanted to put this forward as I'm an experienced technician and thought all was good on my board/ couldn't find the issue/ started looking at various posts and speculations on the topic that suggested it was a Teensy issue etc. etc. Then thought nah...hang on plenty of people not experiencing this... gotta be my issue.
Regards,
Adam

niall-munnelly, 2021-01-17:
> If you want to upload audio samples of the noise we'd be happy to listen and compare to what we know the noise of a normal radio music sounds like. The ideal sound would start with a 0db tone, then have some silence and then end with another tone. Like all Eurorack modules you should experiment with where it is in your case (far away from PSU is a good idea) and also keep it away from very electrically noisy modules (worse culprits are modules with screens, expensive 'conputer' modules and l Those with lots of LEDs). Also if you are using a switching type PSU, the cheap laptop type ones can be very noisy. It's best to work out other strategies first though.
> […](#)

Here's mine. It's not quite what you asked for, and I'm sorry for that, but I think it demonstrates the behavior well enough:

https://www.dropbox.com/h?preview=Radio+Music+Troubleshooting.mp3

It starts with manual triggers, changing the sample. Then there are manual triggers, changing the pitch, and here you can hear the noise changing pitch as well. Finally there's just a quick pass with a sequencer.

This admittedly is something of a "Hail Mary" pass here; I'm just hoping someone will recognize this before I send it off to a tech.

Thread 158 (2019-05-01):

JUST BUZZ at AUDIO OUT

PZHRHG, 2019-05-01:
Hello Community.. I've been looking for a RADIO MUSIC for a while and now finally I have mine .
I've followed instruction ( I believe ) :
_ Loaded Firmware Radio_Music_2017.2.hex using tensy loader as per manual
_ Loaded SD Blank files on a SANDISK ULTRA 16Gb as start up to test module

The module seem to respond to CV signals over the 3 inputs (it blink accordingly) but
at AUDIO Out I get just a low BUZZ .. That it stops after a while ..probably buzz stop when Sample end since on the setting text file LOOPING is set to ZERO.
to clarify , my aim is not disturbing noise over audio.. but the fact that I dont ear samples ! **just this low volume buzz**
Also having upper LEDs setted as sort of VU Meters I see them blinking according Sample Lenght & Amplitude..so it seem that module READ samples correctly

I dont understand what's wrong . The fact that respond to CV and BUZZ go silent make me think that probably I have a problem with samples or settings..
I also tryied to load other mono samples .WAV 44Kh-16bit cutted with soundforge but I always get only BUZZ at Audio out.
I really cannot make it alone . Could You please help me ? Ciao Paolo

_______________________________________________________________________________________

**Added some more details that may be useful to receive answer I need :**

_Are you powering via USB or the eurorack bus? --> EURORACK BUS

_Did you cut the Teensy power --> YES . Infact I CHANGE FIRMAWAREs with power from Eurorack w/o problems (it seem to me)

_If you don't insert the SD card and boot up are any LEDs flashing? --> YES upper red LED blink in sequence from 1 to 4 then again

_Did you follow the guidelines for structuring the folders on the SD card? --> I believe yes just copied the SD Blank from Empty SD Card File Format on the manual.. then also inserted other files but still have same issue

SETTING.TXT
crossfade=0
crossfadeTime=5
showMeter=1
meterHide=2000
chanPotImmediate=0
chanCVImmediate=0
startPotImmediate=0
startCVImmediate=0
startCVDivider=16
looping=0
sort=1
pitchMode=0

PZHRHG, 2019-05-01:
some more details that may be useful to receive answer I need :

_Are you powering via USB or the eurorack bus?  --> EURORACK BUS

_Did you cut the Teensy power --> YES . Infact I CHANGE FIRMAWAREs with power from Eurorack
trace?

_If you don't insert the SD card and boot up are any LEDs flashing?  --> YES upper red LED blink in sequence from 1 to 4 then again

_Did you follow the guidelines for structuring the folders on the SD card? --> I believe yes just copied the
SD Blank from Empty SD Card File Format on the manual.. then also inserted other files but stil have same issue

PZHRHG, 2019-05-04:
Solved. It was my mistake in build

Closed 2019-05-04.

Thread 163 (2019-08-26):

Low Volume, Trimpot At Back Does Nothing

angiamusic, 2019-08-26:
Built a new MTM Radio a while back, worked perfectly for some time, even used it at live gigs, but I recently moved to a new, bigger case and ever since then the output volume has been really low and turning the blue trimpot at the back does nothing. All CV inputs, Reset button and LEDs seem to be working ok, its just the output volume.

For reference, this started when I moved to a new case with a new power supply, I've since resoldered some of the less perfect joints and replaced the TL074CN but nothing made any difference. The volume doesn't change regardless of plugging/unplugging any other CV into the module. Any help would be appreciated.

TomWhitwell, 2019-08-26:
That sounds very odd - if the trimpot does nothing, perhaps it is at fault. That could possibly explain this behaviour.

angiamusic, 2019-08-26:
Perhaps. I thought the same thing and re-soldered the trimpot itself to no avail. Maybe I need to change the trimpot entirely?

Thonk-Steve, 2019-08-26:
It might be worth trying that, maybe check also with a multimeter that
there isn't a short to ground on the output, or measure resistance between
the output signal and ground.

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

angiamusic, 2019-08-26:
> It might be worth trying that, maybe check also with a multimeter that there isn't a short to ground on the output, or measure resistance between the output signal and ground.
> […](#)
> On Mon, Aug 26, 2019 at 1:36 PM angiamusic ***@***.***> wrote: Perhaps. I thought the same thing and re-soldered the trimpot itself to no avail. Maybe I need to change the trimpot entirely? — You are receiving this because you are subscribed to this thread. Reply to this email directly, view it on GitHub <#163?email_source=notifications&email_token=AAKXH6BJCRTD56GS6XQZUZDQGPE3JA5CNFSM4IPPCFQKYY3PNVWWK3TUL52HS4DFVREXG43VMVBW63LNMVXHJKTDN5WW2ZLOORPWSZGOD5EHPHY#issuecomment-524842911>, or mute the thread <https://github.com/notifications/unsubscribe-auth/AAKXH6DG2KUDXJUVH2DZDKDQGPE3JANCNFSM4IPPCFQA> .

Thanks for the reply, I just checked and there's no short to ground on the output.

angiamusic, 2019-08-26:
Alright, I didn't have any potentiometer with me of that trimpot design at the moment, but I again redid the solder joints in a desperate quick fix attempt, and it works fine now! Thank you, Steve and Tom, for your help.

Closed 2019-08-26.

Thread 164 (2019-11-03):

Low volume

oliverhd, 2019-11-03:
I have very low volume coming from chord organ and dont know why. have tried turning pot on the back but does not seem to change. the person i bought it from said he made it so when using the micro usb port for installing firmware it woulndt need eurorack power at the same time. dont know if this affects it, or if i somehow have exeeded the power limiting but other modules work fine.

Thonk-Steve, 2019-11-03:
Hi Oliver,

Do you have DIY skills? If it arrived like this I would send it back to the
person who built it and get them to fix it, this is a soldering issue and
has nothing to do with the USB port or software flashing.

You should hear big changes in volume on the output when turning that
trimmer on the back.

Regards

Steve
Thonk

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

oliverhd, 2019-11-03:
hmm. I have a little experience but will contact the person i bought it from. is the a way to see if the solder is bad? like oxidising?

oliverhd, 2019-11-03:
Thank you :)

Thonk-Steve, 2019-11-04:
Maybe send some photos of both sides of both PCBs?
I meant more that it suggests an issues with either a short circuit, a bad
solder joint, a poor connection between the two PCBs and the Teensy or that
a part has been damaged during the build.

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

oliverhd, 2019-11-04:
wow i fixed it myself, upon further inspection it was clear there was a lose connection since volume came back when pressing the panels a little together in the top. Then i looked for bad soldering or non at all first one of the power connectors had a little hole in the solder blob so i just touched it to heat up an form properly around the hole. then wich was probably the reason one of the resistors had very little if any solder on one of them and i gave it a little and now it works :D  thank you so much for your help

Thonk-Steve, 2019-11-04:
brilliant, well done :)

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

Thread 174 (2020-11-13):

Radio Music will not read SD Card, just fast reset each time

ApocPro, 2020-11-13:
I recently built a Radio Music.  I am having the same issue as electrojuke from 2018.  The module test works as expected, but with the Radio Music firmware loaded, it appears to be unable to read the SD card.  Without the SD card it slowly cycles through the LEDs and resets looking for an SD, but as soon as I put the SD card in it cycles the LEDs super quickly and resets the module with a loud click.  I have tried SanDisk Ultra class 10, class 4, 32 GB, 16GB, 8 GB.  All exhibit the same behavior.  Anyone have any ideas?

TomWhitwell, 2020-11-13:
Hi, sorry to hear that
- Check on the way the SD card is formatted - https://github.com/TomWhitwell/RadioMusic/wiki/SD-Card%3A-Format-and-File-Structure
- Check you have the latest firmware from here: http://www.polyfather.com/radio_music/
- Check soldering on the SD card and on the Teensy
- You could try the Chord Organ firmware to see if that works, less dependent on SD card - might narrow down the issue: http://polyfather.com/chord_organ/

ApocPro, 2020-11-14:
I purchased a brand new SD card, SanDisk Ultra 32GB and added the files.  The previous SD cards I had been using had been used for something else before and I had reformated them using a Mac.  The erase function and Formatting for MS-DOS(FAT) seems to have been part of the issue.  After using a fresh SD as formatted from manufacturer, the Teensy wrote the settings as it was supposed to and hadn't been doing before.

It still had problems reading the files, so I reloaded the firmware as per your link above.  (The firmware that I had downloaded from the Github that was labelled as latest appears to be formatted for the Teensy 3.1 and I am using the 3.2).  After downloading Radio_Music_2017.2.hex everything is functioning as expected.

Thank you for your help and quick response.

Bassliner303, 2021-11-04:
My Radio Music has a similar issue. It simply does not read the SD Card. I tried 3 cards, SanDisk Extreme 32 GB, SanDisk Ultra 32 & 16 GB. No luck with that. Firmware is Radio_Music_2017.2.hex. Keeps resetting in a loop.

Chord Organ however is working.

Thonk-Steve, 2021-11-05:
If Chord Organ firmware is working and Radio Music isn't then that suggest
a possible soldering or mechanical issue with the SD card holder or the
connections between the card holder and the Teensy on the back. Checking
continuity with a multimeter and reflowing any suspect joints between the
SD card holder, through the various board connectors and to the teensy is
the best bet next. Chord Organ only has optional SD card requirements, it
works perfectly well without it working.

If you're using the latest Radio or Chord firmware from
http://www.polyfather.com/ then one good test to do to see if the SD card
can be written to (but perhaps can't be read from) is to hold down the
button while the module boots with an SD card in. If the Teensy is able to
write to the card then it'll put a file called settings.txt onto it. You'll
be able to see this file when you mount the SD card on your computer.

On Thu, Nov 4, 2021 at 6:45 PM Bassliner303 ***@***.***>
wrote:

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

Bassliner303, 2021-11-05:
Thanks for your quick reply. I finally got it working.

I checked the Gerber files, followed the traces and checked continuity with a multimeter. It had nothing to do with the card reader. There has been a bad trace on the pcb which connects the middle pin of the 7 pin connector to one leg of the station potentionmeter. Fixed that with a wire and now its working as it should :-)

Closed 2023-04-05.

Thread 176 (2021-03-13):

Module works briefly after loading firmware then sound rapidly degrades

aaronstevenwhite, 2021-03-13:
I've looked through the issues reporting buzzing and distorted sound, and what I'm experiencing seems to be slightly different. I've replicated the following on both a PGH power supply and an Arturia RackBrute 6U power supply, both with the module alone on the supply and with other modules.

After initially loading new firmware onto the teensy (I've switched back and forth between Radio Music, using the suggested sound library, and the Chord Organ), the module works perfectly for one or two minutes—station, start, and reset all function correctly, LEDs functions correctly, and I get undistorted sound (maybe with some hum) with both firmwares. Then, the sound begins to rapidly degrade into the sort of buzzing reported in a variety of other issues until the buzzing is the only sound that can be heard. When I turn station or press reset, it momentarily affects the buzz.

Powering down for a few minutes and then powering back up does not fix this issue. The only way to "fix" it is to reload the firmware, at which point the sound is perfect again for one or two minutes before degrading in the same way.

TomWhitwell, 2021-03-14:
Sorry to hear that, it sounds very odd.
Have you done the 100k resistor fix? #70 https://github.com/TomWhitwell/RadioMusic/issues/70
It’s possible that a quick power cycle would leave the capacitor charged (distorting) while taking the module out and changing firmware would give it time to dissipate.

aaronstevenwhite, 2021-03-20:
Thank you for the extremely quick response! The resistor 100K fix seems to fix the issue modulo some remaining low-level hum. My apologies for creating a separate issue.

I was under the mistaken impression that that fix was for an older version, and the apparent connection to reloading the firmware (and the short timescale compared to the hours before degradation others reported) made me think this issue was distinct.

I'm still somewhat unsure why it seemed to be linked with swapping out the firmware. I did do quite a bit of testing before posting this issue involving waiting the same amount of time with and without swapping firmware, unplugging the module and letting it sit, and even plugging the module into USB but not swapping out the firmware; and the only thing that made a difference was swapping the firmware. Very odd.

Thanks again for the quick response and apologies again for the superfluous issue. I know how annoying responding to issues with documented fixes can be.

Closed 2021-03-20.

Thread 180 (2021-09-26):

Background noise during playback

Eliad-beep, 2021-09-26:
Hi all,
I bought an assembled RM a couple of years ago and have had this issue since the start. I've tried figuring this out a few times and always failed. Maybe someone here can help.
My module makes a consistent background noise when playing back files. any file. It is faint and in moments of silence (within the sample) it can be very clear. It also has a certain tonality to it so it can be quite distracting.
Here is an example demonstrated by playing the "standard" birds sample that comes with the blank SDcard setup: https://soundcloud.com/eliad-wagner/normal-volume-birds-example/s-2K0ST5W6kbG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

Here is an example of one of my own personal files where I amplified the output quite a bit in order to make the issue clear:
https://soundcloud.com/eliad-wagner/example-1-via-rm/s-6fvKfJPDcg4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

The original file on the SDcard is a 16bit/41khz WAV file and you can hear it here for reference:
https://soundcloud.com/eliad-wagner/example-1-original-16bit-41k/s-4r1Q1nup0HA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

one thing I noticed (and that is why I decided to finally write here) is that when switching to another bank which contains samples of higher sample rate (48k in this case) the tonality of the disturbance seem to double in pitch. see example here:
https://soundcloud.com/eliad-wagner/example-2-via-rm/s-JYSSmNb5dpK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

The original (for comparison) is here: https://soundcloud.com/eliad-wagner/example-2-original-16bit-48k/s-XnYRVJdIRom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
** Please note that the original file in this example is encoded as 16bit/48khz and is also a stereo WAV file (not sure if that matters)

I find the behavior interesting because it possibly hints to the fact that the source of the problem is somewhere in the Teensy chip ? or the mechanism of reading the files?

I made an entire playlist of these example so you could have an easy repetitive listening if you like: https://soundcloud.com/eliad-wagner/sets/rm-issue-debug/s-zaHeIke5ay1

My module has a red rev2 PCB and also has a 100K resistor fix applied to it on the back side of the back PCB (as discussed in issue[#70](https://github.com/TomWhitwell/RadioMusic/issues/70)

Thanks in advance for your help

jaykrizzle, 2022-05-14:
hey there, did you (or others) ever found a solution for this problem?
I have the same behaviour and the red rev2 PCB version and from reading your message it seems that the 100k resistor  doesn't solve the issue, right?

Eliad-beep, 2022-05-15:
Not solved and perhaps widely ignored by makers and users alike. I tried 2 versions of radio music modules with different sim cards, file types, formats... It's always there

Eliad-beep, 2022-05-15:
100k resistor didn't solve it either.
I honestly started thinking that it's my ears that just pick up on it and others don't mind it.
Sold my module and moved on.

jaykrizzle, 2022-05-15:
Thanks for your fast reply!
Yes, i know that some (broadband) noise is normal as in most digital samplers. I have no problem with that. But i doubt that the humming is the normal behaviour of the module… is it? To get a more accurate picture of it, I would be curious to hear from others if they
A) didnt have the humming on their builds
or
B) they have it but they simply not care about it?

And since adding the resistor doesnt help in this regard, is there something that we could do about it - like changing code? Or changing the diy/ hardware side of the module?

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

Vykaar, 2023-02-03:
I have two Radio Music modules with 2.1 pcbs and both caused a low level buzz when connected to other modules. The way I fixed that was to make some leads that only connected the tips of the jacks so no ground loop was being made. I have many Doepfer LC6 and LC9 cases and they both did this in any case but are now quieter if I only connect with single core groundless cables.

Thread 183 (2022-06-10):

Several CV Issues mainly Reset In

PeterSpiegel, 2022-06-10:
I bought a used MTM Radio Music and it functioned a bit strange. The CV in for Reset did not respond to any type of control voltage. The CV start did not seem to respond either. The only CV in that seems to respond is the station. The start position Knob also does not seem to respond and I can't select the banks holding the reset button down.

I updated the firmware to the 2017.2 hex file on a teensy 3.2 board and loaded the standard settings.txt. Unfortunately I still get the same behaviour.

Could it be a build issue and where would I be best approaching it. The only odd solder points are for the pins on the teensy. The other solder work on the 2 boards looks professionally done.

Any advice as to where I should best probe with a multimeter be mich appreciated.

TomWhitwell, 2022-06-10:
Hi, sorry to hear that. If the Teensy pins look dubious I'd start by resoldering those.

PeterSpiegel, 2022-06-10:
Thanks Tom, I'll start from there on in and maybe have a look into some of the resistors with a multimeter. I've seen some issues here with R18 and R19 for the reset in

PeterSpiegel, 2022-06-11:
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

Here are some Fotos of the solder points on the teensy. As you can see I don't think they are done very well. I think this would be a good point to start from. Also the female connector has a break at one point and I'm not sure if that could cause an issue

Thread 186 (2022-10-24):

Reset CV not working, Start CV behaving weird. Also sometimes glitching.

finnglink, 2022-10-24:
Picking up on #183 here, I've taken over from @PeterSpiegel.

I've yet again inspected the board. One of the electrolytic caps was the wrong way around. Fixed that, and reflowed all the joints.
The CV ins are now mostly working. I've also refreshed the latest firmware with a default settings file.

- CV Station is fine
- CV Start works, but on short samples I can go beyond the sample it should play (using a +10V Befaco Joystick as source)
- Reset button, LED and bank change works.
- Reset CV in however, does nothing. I've already swapped the two BAT42s and went through it with a multimeter. I get continuity all the way through, from the jack to the pin on the Teensy. But still, nothing is happening when I plug a gate in there (I've tried 5V and 7V, but I assume 3.3V should be enough to work)

Also, sometimes the sounds seem to glitch out when I feed a CV in there. They still somewhat respond to pots and CV, but can only go back to normal on a power cycle.

Any ideas on where to look next? Could the TL074 be faulty (causing the glitch-hang-up and weird CV behavior), or are some of the Teensys inputs toast?

Best,
Finn

finnglink, 2022-10-24:
This is what I'm at right now:
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

finnglink, 2022-10-24:
Update 2022.10.24 / 15:45:

Swapping the TL074 seems to have fixed the sample jumping on higher start-cv voltages.

With a little code-snippet:
` digitalWrite(11, digitalRead(9)); `
I could verify, that the Reset CV is fully functional, and that it seems to be a software problem.

I've also tried a newly formatted (FAT on Mac, I can only choose between ExFAT and FAT) 32GB SD card with just two samples doesn't change anything. I'm currently on the 2017 Firmware **(Radio_Music_2017.2.hex)**. The older version **RadioMusic1_1.cpp.hex** doesn't work at all. Without an SD card I get the four lights blinking at the same time, with the card inserted it's completely dead.

CallPhysical, 2023-01-29:
Did you ever get it working? I just bought one used and it has the same rev board as yours, but there are two extra resistors that have been added on the back of boards as a fix for something. I wonder if yours needs the same.

finnglink, 2023-01-31:
> Did you ever get it working? I just bought one used and it has the same rev board as yours, but there are two extra resistors that have been added on the back of boards as a fix for something. I wonder if yours needs the same.

I did not, I gave up haha. I don't really have the time for DIY at the moment, so I passed it on to someone from our Discord. Would you take a picture of the resistors I can share with them?

Thonk-Steve, 2023-01-31:
The resistors thing is most likely to resolve a distortion issue that some
people would have when the module is left on for a long time.

It sounds to me like you possibly have a short circuit that's feeding into
the CV system somewhere, did you get your kit from Thonk?

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

finnglink, 2023-01-31:
> It sounds to me like you possibly have a short circuit that's feeding into the CV system somewhere, did you get your kit from Thonk?
> […](#)

Thanks Steve!
I bought it as damaged / failed DIY, I don't know where it's from originally.

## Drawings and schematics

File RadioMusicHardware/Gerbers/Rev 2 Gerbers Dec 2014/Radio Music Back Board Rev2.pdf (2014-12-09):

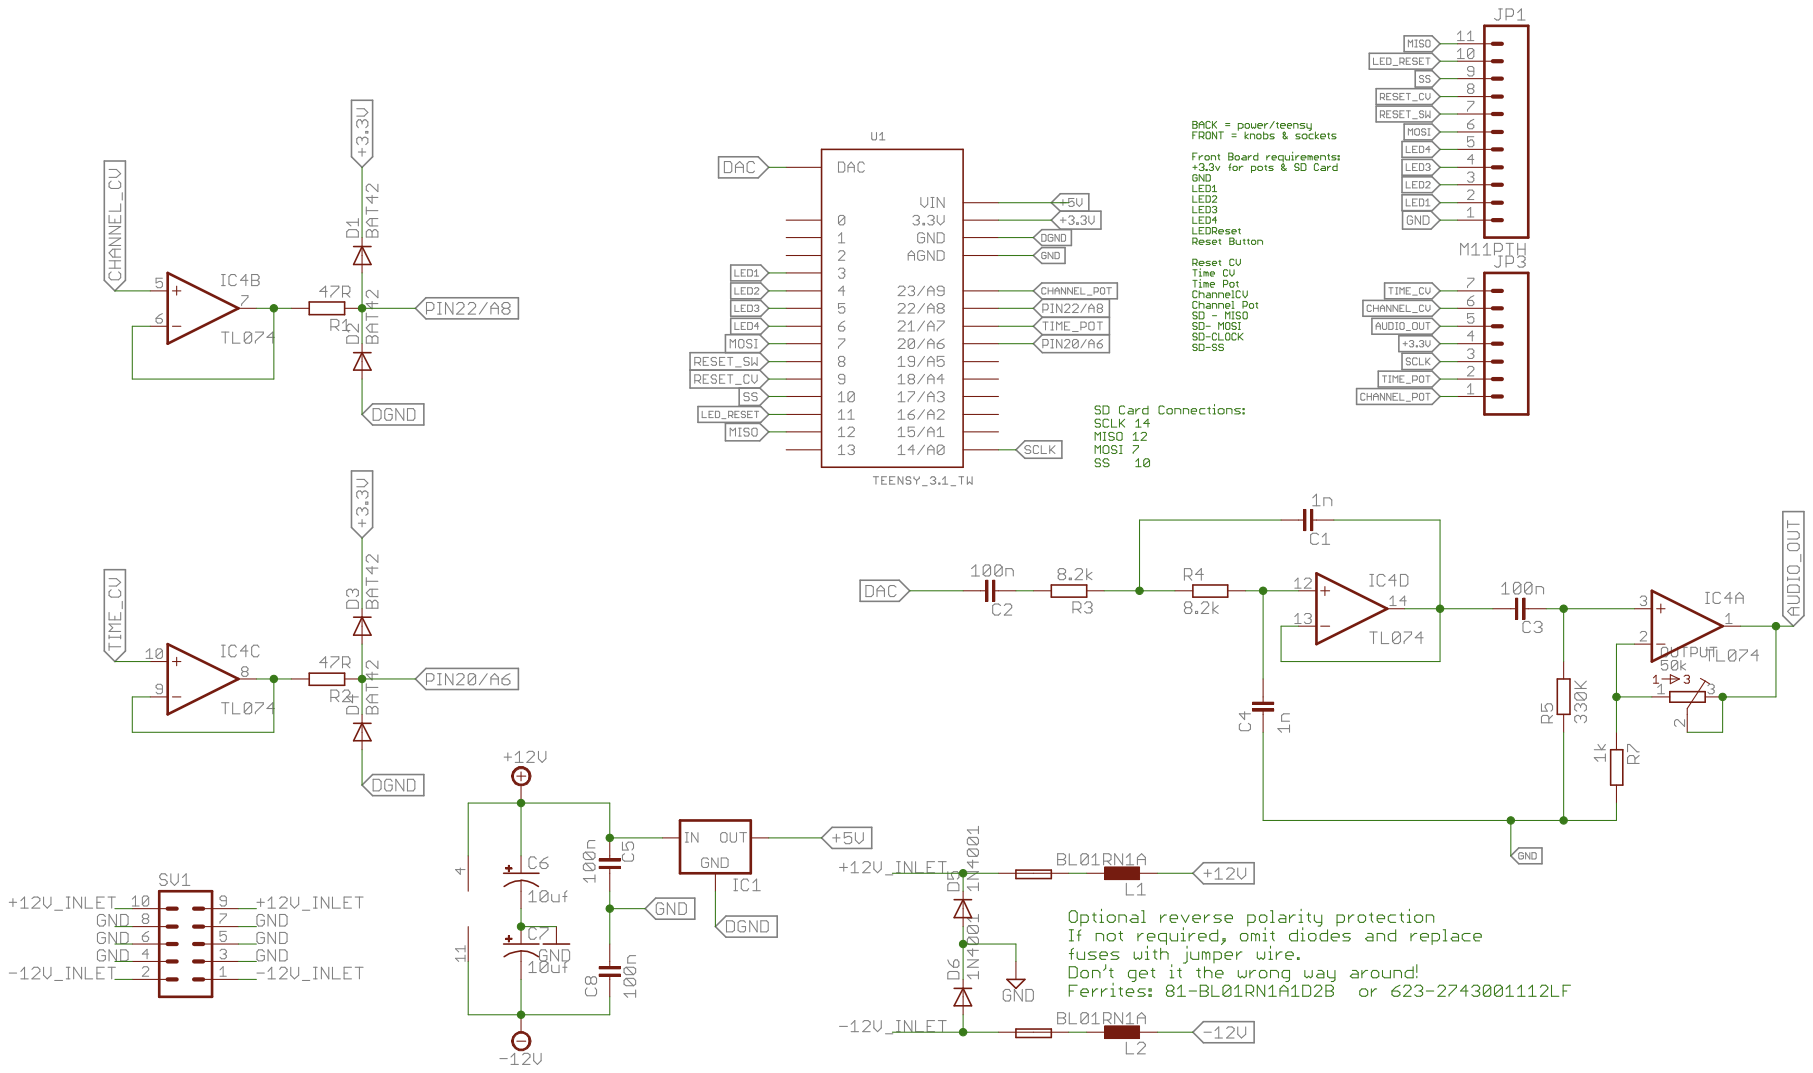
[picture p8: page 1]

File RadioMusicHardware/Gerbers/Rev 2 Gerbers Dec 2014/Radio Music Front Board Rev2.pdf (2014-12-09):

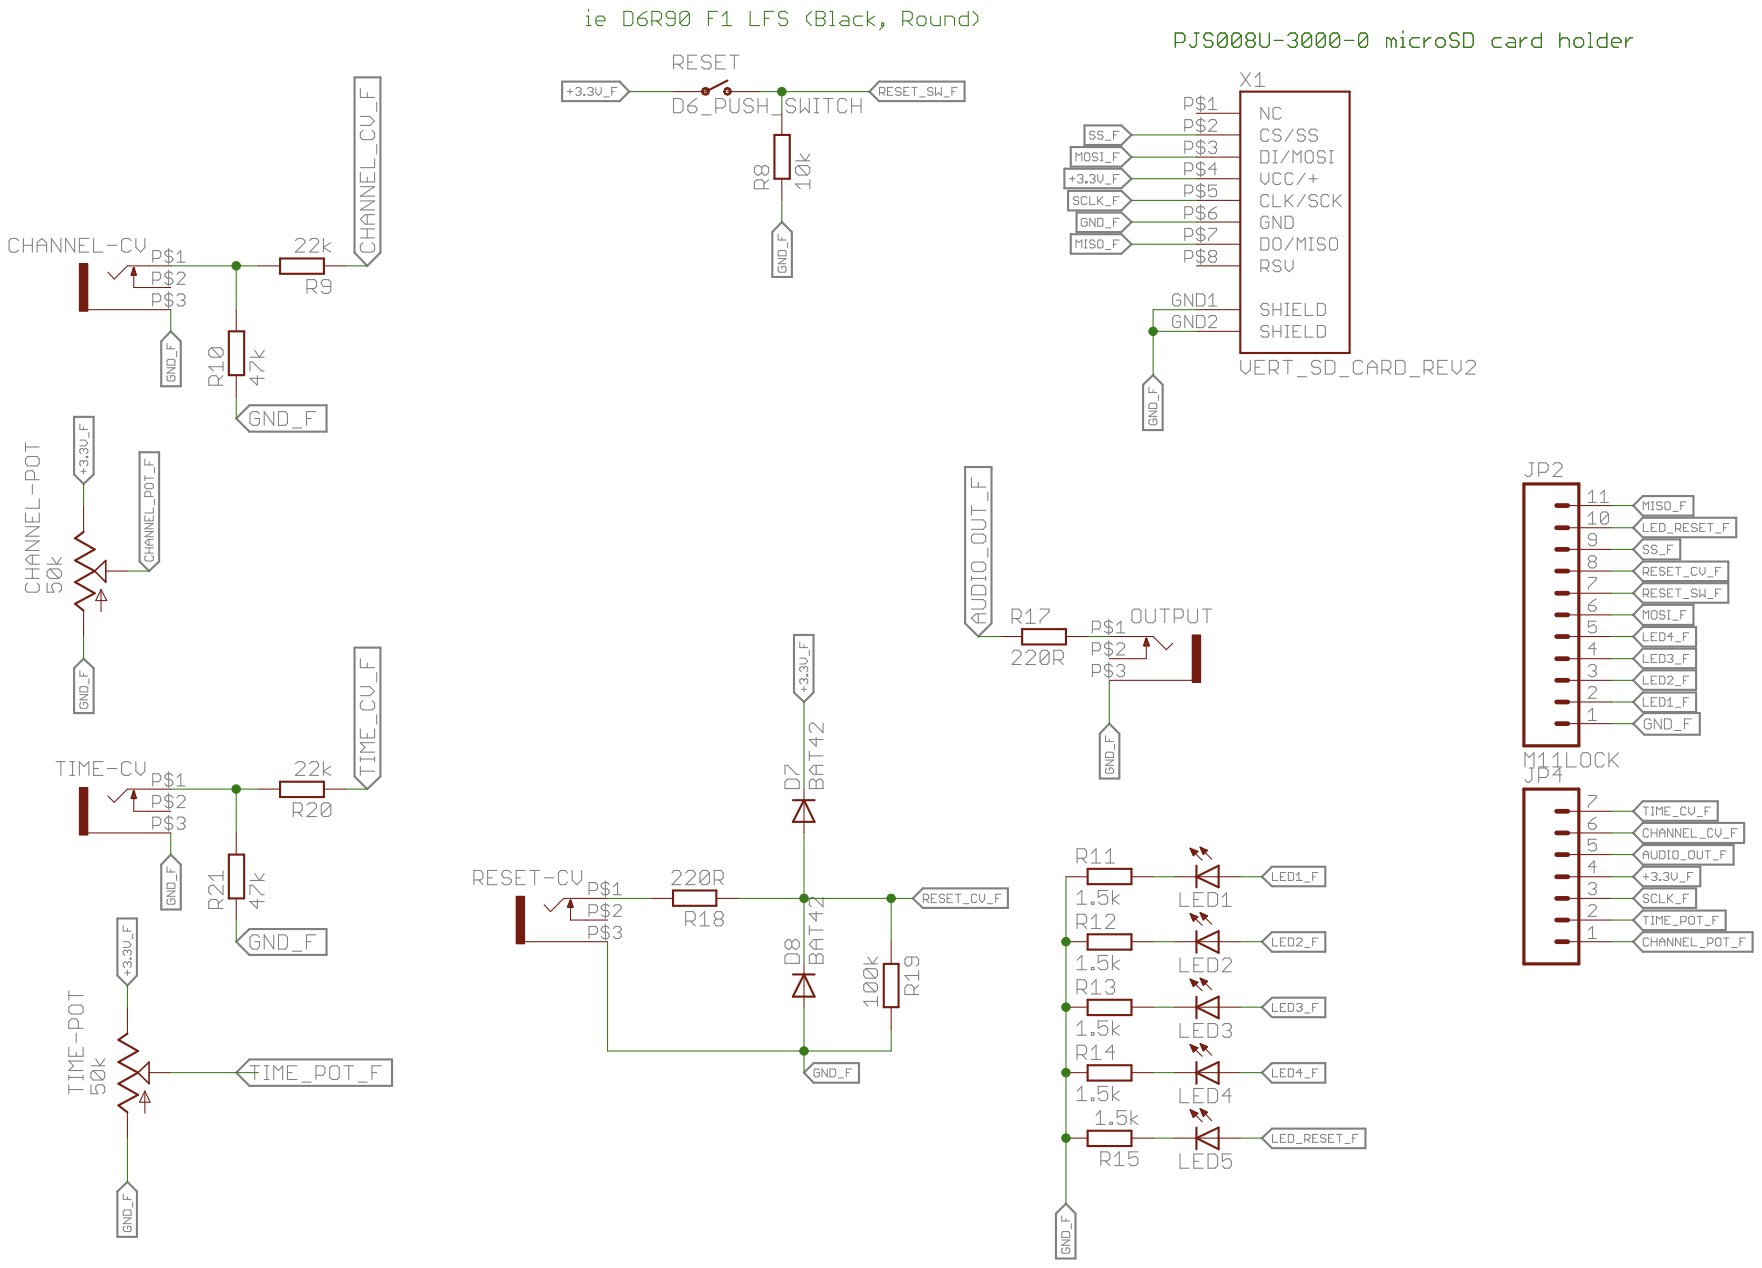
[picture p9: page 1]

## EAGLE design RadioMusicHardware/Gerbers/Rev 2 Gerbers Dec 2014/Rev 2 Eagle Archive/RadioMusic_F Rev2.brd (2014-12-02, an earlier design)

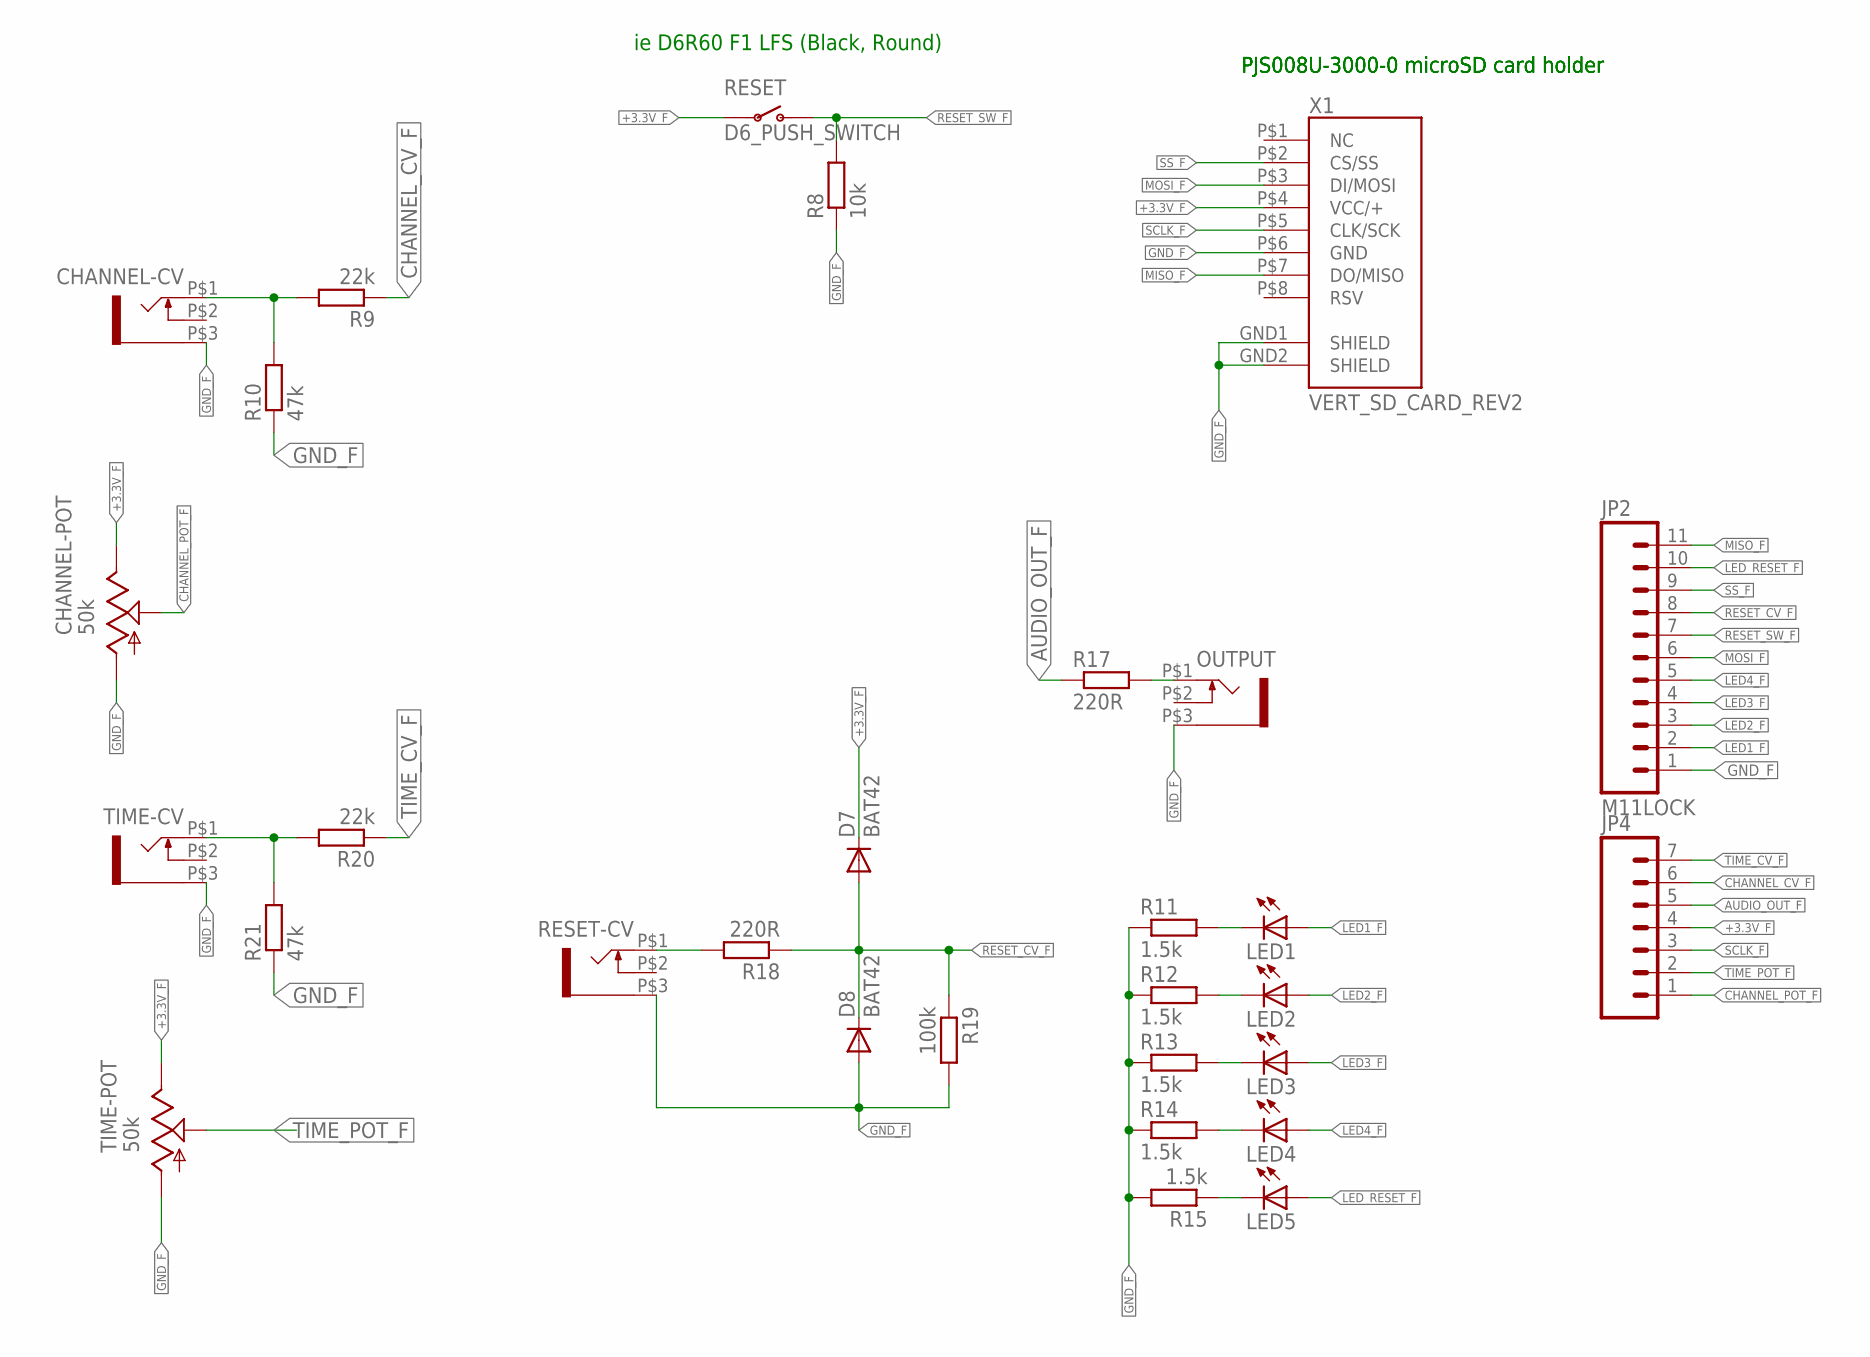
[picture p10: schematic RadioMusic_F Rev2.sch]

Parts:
CHANNEL-CV: WQP-PJ301M-12_JACK
CHANNEL-POT: 50k; EVUF
D7, D8: BAT42; DO34-7
JP2: M11LOCK; 1X11_LOCK
JP4: M07LOCK; 1X07_LOCK
LED1, LED2, LED3, LED4, LED5: LED3MM
OUTPUT: WQP-PJ301M-12_JACK
R8: 10k; 0207/10
R9, R20: 22k; 0207/10
R10, R21: 47k; 0207/10
R11, R12, R13, R14, R15: 1.5k; 0207/10
R17, R18: 220R; 0207/10
R19: 100k; 0207/10
RESET: D6_PUSH_SWITCH; D6_BUTTON_RND
RESET-CV: WQP-PJ301M-12_JACK
TIME-CV: WQP-PJ301M-12_JACK
TIME-POT: 50k; EVUF
X1: VERT_SD_CARD_REV2; VERT_MICROSD_REV2

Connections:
+3.3V_F: CHANNEL-POT.3 (E), D7.C, JP4.4, RESET.P$3, RESET.P$4, TIME-POT.3 (E), X1.P$4 (VCC/+)
AUDIO_OUT_F: JP4.5, R17.1
CHANNEL_CV_F: JP4.6, R9.1
CHANNEL_POT_F: CHANNEL-POT.2 (S), JP4.1
GND_F: CHANNEL-CV.P$3 (1), CHANNEL-POT.1 (A), D8.A, JP2.1, OUTPUT.P$3 (1), R8.1, R10.1, R11.1, R12.1, R13.1, R14.1, R15.2, R19.2, R21.1, RESET-CV.P$3 (1), TIME-CV.P$3 (1), TIME-POT.1 (A), X1.GND1 (SHIELD), X1.GND2 (SHIELD), X1.P$6 (GND)
LED1_F: JP2.2, LED1.A
LED2_F: JP2.3, LED2.A
LED3_F: JP2.4, LED3.A
LED4_F: JP2.5, LED4.A
LED_RESET_F: JP2.10, LED5.A
MISO_F: JP2.11, X1.P$7 (DO/MISO)
MOSI_F: JP2.6, X1.P$3 (DI/MOSI)
unnamed: OUTPUT.P$1 (2), R17.2
unnamed: CHANNEL-CV.P$1 (2), R9.2, R10.2
unnamed: R18.2, RESET-CV.P$1 (2)
unnamed: LED1.K (C), R11.2
unnamed: LED2.K (C), R12.2
unnamed: LED3.K (C), R13.2
unnamed: LED4.K (C), R14.2
unnamed: LED5.K (C), R15.1
RESET_CV_F: D7.A, D8.C, JP2.8, R18.1, R19.1
RESET_SW_F: JP2.7, R8.2, RESET.P$1 (O), RESET.P$2 (O)
SCLK_F: JP4.3, X1.P$5 (CLK/SCK)
SS_F: JP2.9, X1.P$2 (CS/SS)
TEMP: R20.2, R21.2, TIME-CV.P$1 (2)
TIME_CV_F: JP4.7, R20.1
TIME_POT_F: JP4.2, TIME-POT.2 (S)

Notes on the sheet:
ie D6R60 F1 LFS (Black, Round)
PJS008U-3000-0 microSD card holder

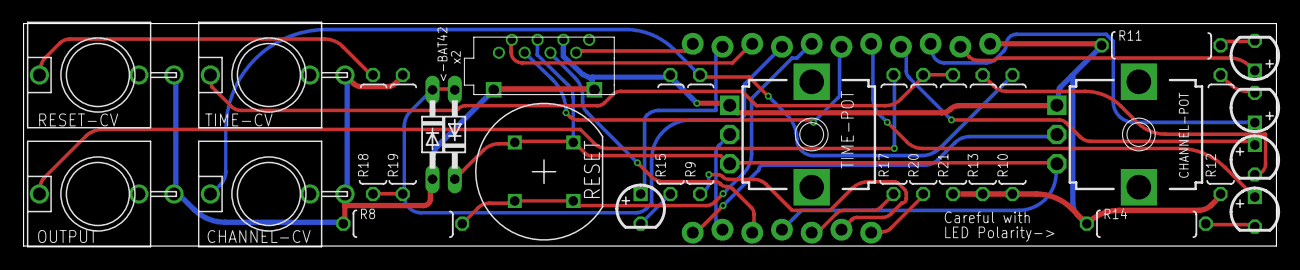
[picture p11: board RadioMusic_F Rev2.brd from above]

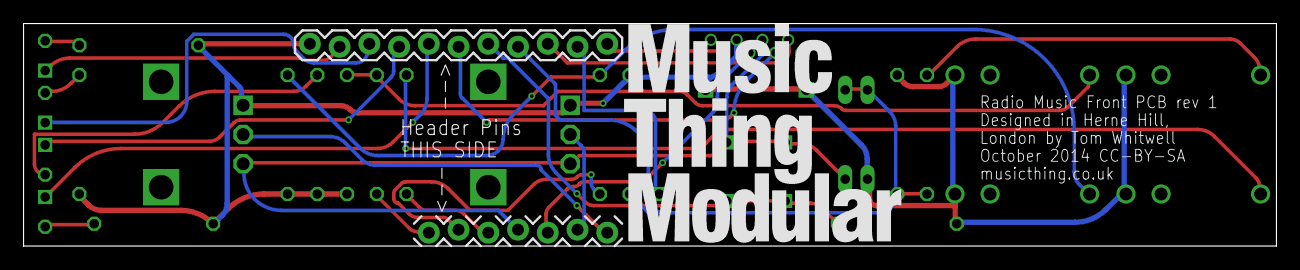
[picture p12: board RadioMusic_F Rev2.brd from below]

Board: 4 copper layers, 107.0 x 19.0 mm, 31 parts (3 on the bottom side), 27 nets.

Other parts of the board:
U$1: MTM_2CM

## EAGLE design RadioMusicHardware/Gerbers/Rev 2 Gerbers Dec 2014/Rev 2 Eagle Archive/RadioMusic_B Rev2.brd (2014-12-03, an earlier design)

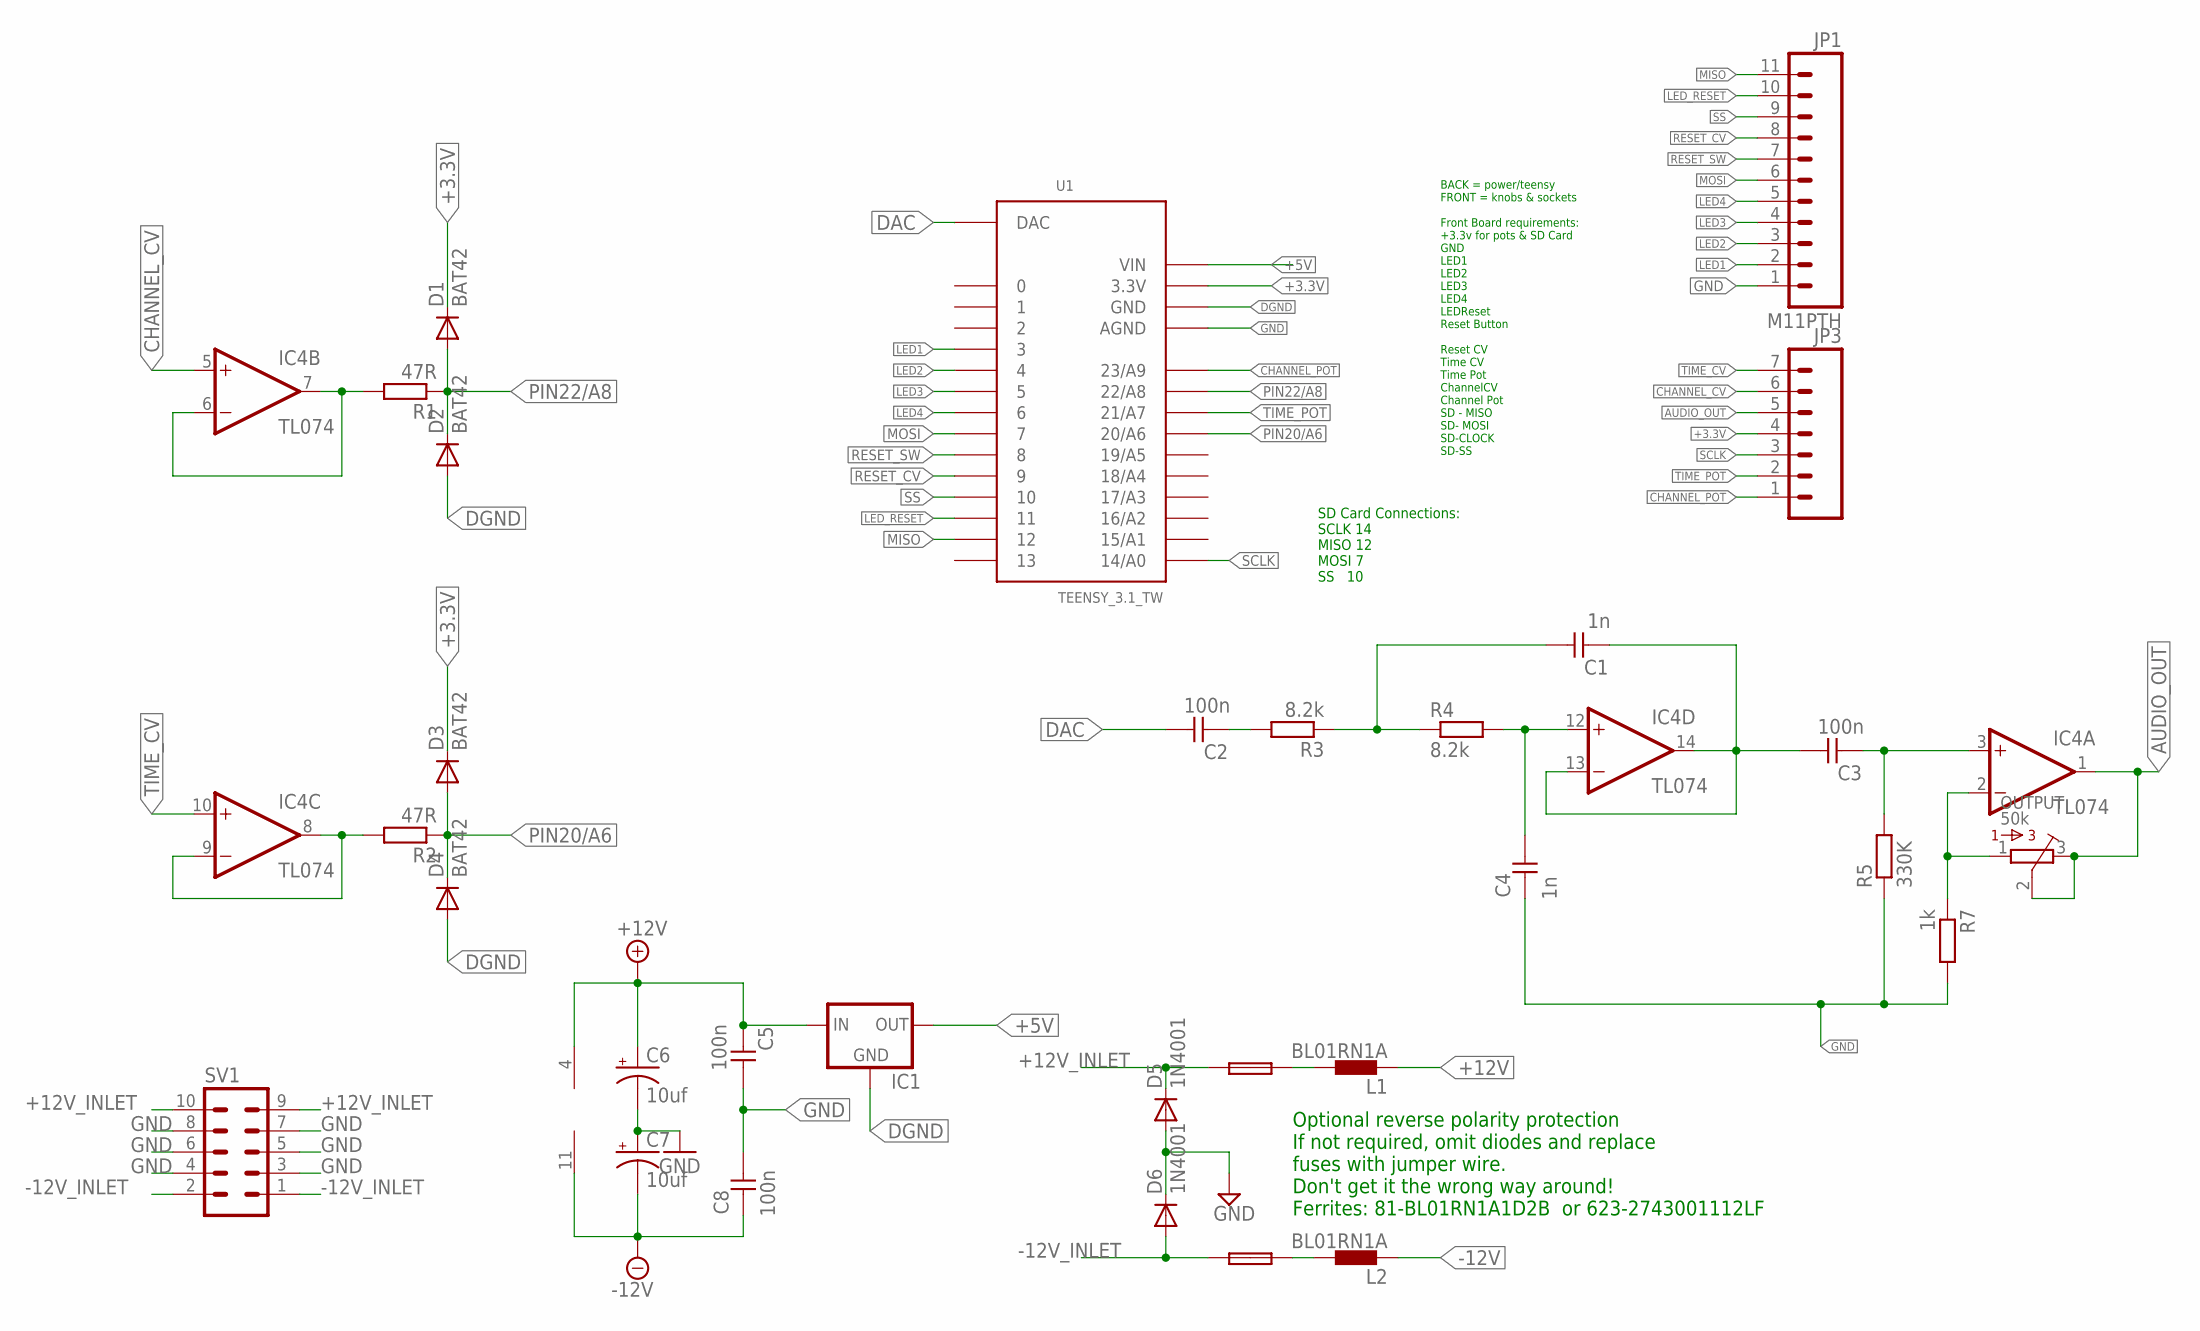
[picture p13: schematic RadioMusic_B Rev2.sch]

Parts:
C1, C4: 1n; C050-024X044
C2, C3: 100n; C050-025X075
C5, C8: 100n; C050-024X044
C6, C7: 10uf; CPOL-RADIAL-10UF-25V
D1, D2, D3, D4: BAT42; DO34-7
D5, D6: 1N4001; DO41-10
F1, F2: FUSE; C050H075X075
IC1: 78LXX
IC4: TL074; DIL14
JP1: M11PTH; 1X11
JP3: M07; 1X07
L1, L2: BL01RN1A
OUTPUT: 50k; 3362P
R1, R2: 47R; 0207/10
R3, R4: 8.2k; 0207/10
R5: 330K; 0207/10
R7: 1k; 0207/10
SV1: 10_PIN_HEADER; MA05-2
U1: TEENSY_3.1_TW

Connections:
+3.3V: D1.C, D3.C, JP3.4, U1.3.3V
+5V: IC1.OUT, U1.VIN
+12V: C5.2, C6.1 (+), IC1.IN, IC4.4 (V+), L1.1
+12V_INLET: D5.C, F1.1, SV1.9, SV1.10
-12V: C7.2 (-), C8.2, IC4.11 (V-), L2.1
-12V_INLET: D6.A, F2.1, SV1.1, SV1.2
AUDIO_OUT: IC4.1 (OUT), JP3.5, OUTPUT.2, OUTPUT.3
CHANNEL_CV: IC4.5 (+IN), JP3.6
CHANNEL_POT: JP3.1, U1.23/A9
DAC: C2.1, U1.DAC
DGND: D2.A, D4.A, IC1.GND, U1.GND
GND: C4.2, C5.1, C6.2 (-), C7.1 (+), C8.1, D5.A, D6.C, JP1.1, R5.1, R7.2, SV1.3, SV1.4, SV1.5, SV1.6, SV1.7, SV1.8, U1.AGND
LED1: JP1.2, U1.3
LED2: JP1.3, U1.4
LED3: JP1.4, U1.5
LED4: JP1.5, U1.6
LED_RESET: JP1.10, U1.11
MISO: JP1.11, U1.12
MOSI: JP1.6, U1.7
unnamed: IC4.8 (OUT), IC4.9 (-IN), R2.2
unnamed: C4.1, IC4.12 (+IN), R4.2
unnamed: IC4.6 (-IN), IC4.7 (OUT), R1.2
unnamed: C1.1, R3.1, R4.1
unnamed: C1.2, C3.1, IC4.13 (-IN), IC4.14 (OUT)
unnamed: C3.2, IC4.3 (+IN), R5.2
unnamed: IC4.2 (-IN), OUTPUT.1, R7.1
unnamed: C2.2, R3.2
unnamed: F1.2, L1.2
unnamed: F2.2, L2.2
PIN20/A6: D3.A, D4.C, R2.1, U1.20/A6
PIN22/A8: D1.A, D2.C, R1.1, U1.22/A8
RESET_CV: JP1.8, U1.9
RESET_SW: JP1.7, U1.8
SCLK: JP3.3, U1.14/A0
SS: JP1.9, U1.10
TIME_CV: IC4.10 (+IN), JP3.7
TIME_POT: JP3.2, U1.21/A7

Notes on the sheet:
Optional reverse polarity protection If not required, omit diodes and replace fuses with jumper wire. Don't get it the wrong way around! Ferrites: 81-BL01RN1A1D2B or 623-2743001112LF
SD Card Connections: SCLK 14 MISO 12 MOSI 7 SS 10
BACK = power/teensy FRONT = knobs & sockets Front Board requirements: +3.3v for pots & SD Card GND LED1 LED2 LED3 LED4 LEDReset Reset Button Reset CV Time CV Time Pot ChannelCV Channel Pot SD - MISO SD- MOSI SD-CLOCK SD-SS

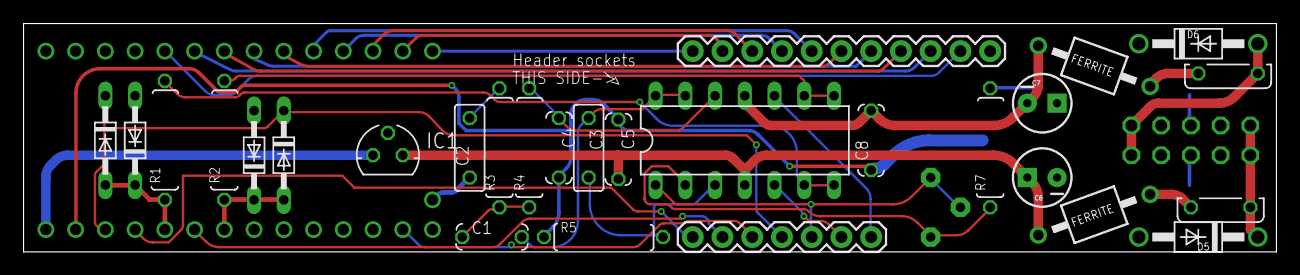
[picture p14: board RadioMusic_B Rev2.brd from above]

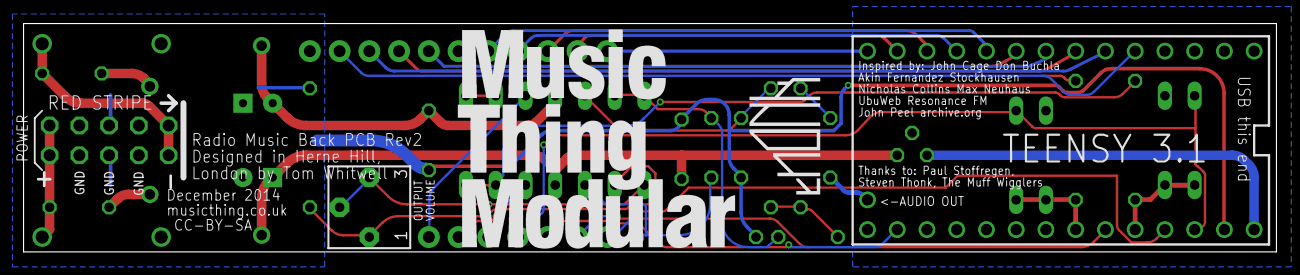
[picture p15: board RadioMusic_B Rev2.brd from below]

Board: 4 copper layers, 107.0 x 19.5 mm, 33 parts (5 on the bottom side), 37 nets.

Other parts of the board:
U$2: THONK_1CM_SCREENPRINT
U$4: MTM_2CM

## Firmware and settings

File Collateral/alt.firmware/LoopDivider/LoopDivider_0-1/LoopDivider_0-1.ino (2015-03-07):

/*
Loop Divider  
 Audio out: Onboard DAC, teensy3.1 pin A14/DAC
 
 Bank Button: 2
 Bank LEDs 3,4,5,6
 Reset Button: 8  
 Reset LED 11 
 Pulse CV output: 9 
 Channel Pot: A9 
 Channel CV: A8 // check 
 Divider Pot: A7 
 Divider CV: A6 // check 
 SD Card Connections: 
 SCLK 14
 MISO 12
 MOSI 7 
 SS   10 
 
 NB: Compile using modified versions of: 
 SD.cpp (found in the main Arduino package) 
 play_sd_raw.cpp  - In Teensy Audio Library 
 play_sc_raw.h    - In Teensy Audio Library 
 
 from:https://github.com/TomWhitwell/RadioMusic/tree/master/Collateral/Edited%20teensy%20files
 
 
 */

#include <EEPROM.h>
#include <Bounce.h>
#include <Audio.h>
#include <SPI.h>
#include <SD.h>
#include <Wire.h>


// OPTIONS TO READ FROM THE SD CARD, WITH DEFAULT VALUES 
boolean MUTE = false;                // Softens clicks when changing channel / position, at cost of speed. Fade speed is set by DECLICK 
int DECLICK= 15;                      // milliseconds of fade in/out on switching 
boolean ShowMeter = true;            // Does the VU meter appear?  
int meterHIDE = 2000;                // how long to show the meter after bank change in Milliseconds 
boolean ChanPotImmediate = true;     // Settings for Pot / CV response.
boolean ChanCVImmediate = true;      // TRUE means it jumps directly when you move or change.
boolean StartPotImmediate = false;   // FALSE means it only has an effect when RESET is pushed or triggered 
boolean StartCVImmediate = false; 
int StartCVDivider = 2;              // Changes sensitivity of Start control. 1 = most sensitive, 512 = lest sensitive (i.e only two points) 
boolean Looping = true;              // When a file finishes, start again from the beginning 
File settingsFile;




// GUItool: begin automatically generated code
AudioPlaySdRaw           playRaw1;       //xy=131,81
AudioEffectFade          fade1;          //xy=257,169
AudioAnalyzePeak         peak1;          //xy=317,123
AudioOutputAnalog        dac1;           //xy=334,98
AudioConnection          patchCord1(playRaw1, fade1);
AudioConnection          patchCord2(fade1, dac1);
AudioConnection          patchCord3(playRaw1, peak1);
// GUItool: end automatically generated code

// REBOOT CODES 
#define RESTART_ADDR       0xE000ED0C
#define READ_RESTART()     (*(volatile uint32_t *)RESTART_ADDR)
#define WRITE_RESTART(val) ((*(volatile uint32_t *)RESTART_ADDR) = (val))

// SETUP VARS TO STORE DETAILS OF FILES ON THE SD CARD 
#define MAX_FILES 150 // Maximum number of files per bank 
#define MAX_BANKS 32 // Maximum number of banks 
int ACTIVE_BANKS = 0; // How many directories are accessible. Directory structure must start at "0" and be sequential 0, 1, 2, 3 etc 
String FILE_TYPE = "RAW"; // only looking for .raw files 
File root;
String FILE_NAMES[MAX_FILES+1]; // Array to hold the file names in the active bank 
unsigned long FILE_SIZES[MAX_FILES+1]; // Array to hold file sizes in the active bank 
int FILE_COUNT;
#define BLOCK_SIZE 2 // size of blocks to read - must be more than 1, performance might improve with 16?


// SETUP VARS TO STORE CONTROLS 
#define CHAN_POT_PIN A9 // pin for Channel pot
#define CHAN_CV_PIN A6 // pin for Channel CV 
#define TIME_POT_PIN A7 // pin for Time pot
#define TIME_CV_PIN A8 // pin for Time CV
#define RESET_BUTTON 8 // Reset button 
#define RESET_LED 11 // Reset LED indicator 
#define RESET_CV 9 // Reset pulse input 
boolean CHAN_CHANGED = true; 
boolean RESET_CHANGED = false; 
Bounce resetSwitch = Bounce( RESET_BUTTON, 20 ); // Bounce setup for Reset
int PLAY_CHANNEL; 
int NEXT_CHANNEL; 
unsigned long playhead;
char* charFilename;

// BANK SWITCHER SETUP 
#define BANK_BUTTON 2 // Bank Button 
#define LED0 6
#define LED1 5
#define LED2 4
#define LED3 3
Bounce bankSwitch = Bounce( BANK_BUTTON, 20 ); 
int PLAY_BANK = 0; 
#define BANK_SAVE 0

// CHANGE HOW INTERFACE REACTS 
int chanHyst = 3; // how many steps to move before making a change (out of 1024 steps on a reading) 
int timHyst = 6; 

elapsedMillis chanChanged; 
elapsedMillis timChanged; 
int sampleAverage = 40;
int chanPotOld;
int chanCVOld;
int timPotOld;
int timCVOld;
#define FLASHTIME 10 // How long do LEDs flash for? 
#define HOLDTIME 400 // How many millis to hold a button to get 2ndary function? 
elapsedMillis showDisplay; // elapsedMillis is a special variable in Teensy - increments every millisecond 
int showFreq = 250; // how many millis between serial Debug updates 
elapsedMillis resetLedTimer = 0;
elapsedMillis bankTimer = 0;
elapsedMillis checkI = 0; // check interface 
int checkFreq = 10; // how often to check the interface in Millis 

// CONTROL THE PEAK METER DISPLAY 
elapsedMillis meterDisplay; // Counter to hide MeterDisplay after bank change 
elapsedMillis fps; // COUNTER FOR PEAK METER FRAMERATE 
#define peakFPS 12   //  FRAMERATE FOR PEAK METER 

//PULSE OUT SYSTEM 
elapsedMillis pulseFlash; // counter for the length of each pulse 
elapsedMillis pulseTime; // counter for the gaps between pulses 
int pFlash = 10; // how long are the pulses? 
int pTime = 500; // how long are gaps between pulses? 


////////////////////////////////////////////////////
///////////////SETUP////////////////////////////////
////////////////////////////////////////////////////


void setup() {

  //DEFINE PINS FOR BANK SWITCH AND LEDS 
  pinMode(BANK_BUTTON,INPUT);
  pinMode(RESET_BUTTON, INPUT);
  pinMode(RESET_CV, OUTPUT);
  pinMode(RESET_LED, OUTPUT);
  pinMode(LED0,OUTPUT);
  pinMode(LED1,OUTPUT);
  pinMode(LED2,OUTPUT);
  pinMode(LED3,OUTPUT);
  ledWrite(PLAY_BANK);

  // START SERIAL MONITOR   
  Serial.begin(38400); 
  delay(1000);

  // MEMORY REQUIRED FOR AUDIOCONNECTIONS   
  AudioMemory(5);
  // SD CARD SETTINGS FOR AUDIO SHIELD 
  SPI.setMOSI(7);
  SPI.setSCK(14);

  // OPEN SD CARD 
  int crashCountdown; 
  if (!(SD.begin(10))) {
    while (!(SD.begin(10))) {
      ledWrite(15);
      delay(100);
      ledWrite(0);
      delay(100);
      crashCountdown++;
      if (crashCountdown > 6)     reBoot();

    }
  }

  // READ SETTINGS FROM SD CARD 

  root = SD.open("/");  

  if (SD.exists("settings.txt")) {
    readSDSettings();
  }

  else { 
    writeSDSettings();
  };


  // OPEN SD CARD AND COUNT THE NUMBER OF AVAILABLE BANKS  
  ACTIVE_BANKS = countDirectory();
  Serial.print (ACTIVE_BANKS);
  Serial.println(" banks found");

  // CHECK  FOR SAVED BANK POSITION 
  int a = 0;
  a = EEPROM.read(BANK_SAVE);
  if (a >= 0 && a < ACTIVE_BANKS-1){
    PLAY_BANK = a;
    CHAN_CHANGED = true;
  }
  else {
    EEPROM.write(BANK_SAVE,0);
  };

  Serial.print("Open bank");
  Serial.println (PLAY_BANK);


  FILE_COUNT = loadFiles(PLAY_BANK);

  Serial.print (FILE_COUNT);
  Serial.print(" files found in bank ");
  Serial.println (PLAY_BANK);


  // Add an interrupt on the RESET_CV pin to catch rising edges
  //  attachInterrupt(RESET_CV, resetcv, RISING);
}

//// Called by interrupt on rising edge, for RESET_CV pin
//void resetcv() {
//  RESET_CHANGED = true;
//}

////////////////////////////////////////////////////
///////////////MAIN LOOP//////////////////////////
////////////////////////////////////////////////////

void loop() {
  //////////////////////////////////////////
  // IF FILE ENDS, RESTART FROM THE BEGINNING 
  //////////////////////////////////////////
  Serial.println (resetLedTimer);
  if (!playRaw1.isPlaying() && Looping){
    charFilename = buildPath(PLAY_BANK,PLAY_CHANNEL);
    playRaw1.playFrom(charFilename,0);   // change audio
    resetLedTimer = 0; // turn on Reset LED 
    pulseTime = 0;
    pulseFlash = 0;

  }

  if (playRaw1.failed){
    reBoot();
  }




  //////////////////////////////////////////
  ////////REACT TO ANY CHANGES /////////////
  //////////////////////////////////////////


  if (CHAN_CHANGED || RESET_CHANGED){
    if (MUTE){  
      fade1.fadeOut(DECLICK);      // fade out before change 
      delay(DECLICK);
    }

    charFilename = buildPath(PLAY_BANK,NEXT_CHANNEL);
    PLAY_CHANNEL = NEXT_CHANNEL;


    if (RESET_CHANGED == false && Looping) playhead = playRaw1.fileOffset(); // Carry on from previous position, unless reset pressed or time selected
    playhead = (playhead / 16) * 16; // scale playhead to 16 step chunks 
    playRaw1.playFrom(charFilename,playhead);   // change audio
    //    delay(10);

    if (MUTE)    fade1.fadeIn(DECLICK);                          // fade back in   
    ledWrite(PLAY_BANK);
    CHAN_CHANGED = false;
    RESET_CHANGED = false; 
    resetLedTimer = 0; // turn on Reset LED 
    pulseTime = 0; 
    pulseFlash = 0; 
  }



  //////////////////////////////////////////
  // CHECK INTERFACE  & UPDATE DISPLAYS/////  
  //////////////////////////////////////////

  if (checkI >= checkFreq){
    checkInterface(); 
    checkI = 0;  
  }

  if (showDisplay > showFreq){
    //    playDisplay();
    //    whatsPlaying();
    showDisplay = 0;
  }

  if (PLAY_BANK < 16){

    digitalWrite(RESET_LED, resetLedTimer < FLASHTIME); // flash reset LED 
  }
  else{
    digitalWrite(RESET_LED, resetLedTimer > FLASHTIME); // flash reset LED 

  }

  if (fps > 1000/peakFPS && meterDisplay > meterHIDE && ShowMeter) peakMeter();    // CALL PEAK METER   


  //////////////////////////////////////////
  //////////// LOOP DIVIDER SYSTEM /////////  
  //////////////////////////////////////////

  digitalWrite(RESET_CV, pulseFlash < pFlash);
  if (pulseTime > pTime){
    pulseTime = 0; 
    pulseFlash = 0; 
  }



}

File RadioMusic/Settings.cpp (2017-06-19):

#include <SD.h>
#include "Settings.h"

#include "RadioMusic.h"

#ifdef DEBUG_SETTINGS
#define D(x) x
#else
#define D(x)
#endif

Settings::Settings(const char* filename) {
	_filename = filename;
}

void Settings::init(boolean hasSD) {

	if (!hasSD) {
		// Configure defaults
		copyDefaults();
	} else {
		if (SD.exists(_filename)) {
			read();
		} else {
			write();
			read();
		};
	}
}

void Settings::copyDefaults() {

}

void Settings::read() {

	D(Serial.println("Reading settings.txt"););

	char character;
	String settingName;
	String settingValue;
	settingsFile = SD.open("settings.txt");

	uint8_t NAME = 1;
	uint8_t VALUE = 2;
	uint8_t state = NAME;

	if (settingsFile) {
		while (settingsFile.available()) {
			character = settingsFile.read();
			if(state == NAME) {
				if(character == '=') {
					state = VALUE;
				} else {
					settingName = settingName + character;
				}
			} else if(state == VALUE) {
				if(character == '\n') {
					applySetting(settingName, settingValue);
					settingName = "";
					settingValue = "";
					state = NAME;
				} else {
					settingValue = settingValue + character;
				}
			}
		}
		if(settingName.length() > 0 && settingValue.length() > 0) {
			applySetting(settingName, settingValue);
		}
		// close the file:
		settingsFile.close();
	} else {
		// if the file didn't open, print an error:
		Serial.println("error opening settings.txt");
	}
	// Do test settings here

//	crossfade = true;
//	crossfadeTime = 1000;
//	looping = false;
//	anyAudioFiles = true;
//	hardSwap = true;
//	chanPotImmediate = false;
//	chanCVImmediate = false;
//	quantizeNote = true;
//	startCVImmediate = true;
//	startPotImmediate = true;
//	quantiseRootPot = true;
//	quantiseRootCV = true;
//	pitchMode = true;
//	startCVDivider = 1;

#ifdef TEST_RADIO_MODE
	radioMode();
#endif

#ifdef TEST_DRUM_MODE
	drumMode();
#endif

	if(!loopMode) {
		if(pitchMode) {
			loopMode = LOOP_MODE_START_POINT;
		} else {
			loopMode = LOOP_MODE_RADIO;
		}
	}

	D(Serial.print("Loop mode ");Serial.println(loopMode););

	if(anyAudioFiles || pitchMode) {
		hardSwap = true;
	}
}

void Settings::drumMode() {
	crossfade=0;
	crossfadeTime=100;
	showMeter=1;
	meterHide=2000;
	chanPotImmediate=1;
	chanCVImmediate=1;
	startPotImmediate=1;
	startCVImmediate=1;
	startCVDivider=1;
	looping=1;
	sort=1;
	pitchMode=1;
	hardSwap = true;
	anyAudioFiles = true;
	loopMode = LOOP_MODE_START_POINT;
}

void Settings::radioMode() {
	crossfade=1;
	crossfadeTime=100;
	showMeter=1;
	meterHide=2000;
	chanPotImmediate=1;
	chanCVImmediate=1;
	startPotImmediate=0;
	startCVImmediate=0;
	startCVDivider=2;
	looping=1;
	sort=1;
	pitchMode=0;
	hardSwap = false;
	anyAudioFiles = false;
	loopMode = LOOP_MODE_RADIO;
}
/* Apply the value to the parameter by searching for the parameter name
 Using String.toInt(); for Integers
 toFloat(string); for Float
 toBoolean(string); for Boolean
 */
void Settings::applySetting(String settingName, String settingValue) {

	D(
	Serial.print(settingName);
	Serial.print(" -> ");
	Serial.println(settingValue);
	);

	if (settingName.equalsIgnoreCase("mute") || settingName.equalsIgnoreCase("crossfade")) {
		crossfade = toBoolean(settingValue);
	}

	if (settingName.equalsIgnoreCase("declick") || settingName.equalsIgnoreCase("crossfadeTime")) {
		crossfadeTime = settingValue.toInt();
	}

	if (settingName.equalsIgnoreCase("showMeter")) {
		showMeter = toBoolean(settingValue);
	}

	if (settingName.equalsIgnoreCase("meterHide")) {
		meterHide = settingValue.toInt();
	}

	if (settingName.equalsIgnoreCase("chanPotImmediate")) {
		chanPotImmediate = toBoolean(settingValue);
	}

	if (settingName.equalsIgnoreCase("chanCVImmediate")) {
		chanCVImmediate = toBoolean(settingValue);
	}

	if (settingName.equalsIgnoreCase("startPotImmediate")) {
		startPotImmediate = toBoolean(settingValue);
	}

	if (settingName.equalsIgnoreCase("startCVImmediate")) {
		startCVImmediate = toBoolean(settingValue);
	}

	if (settingName.equalsIgnoreCase("startCVDivider")) {
		startCVDivider = settingValue.toInt();
	}

	if (settingName.equalsIgnoreCase("looping")) {
		looping = toBoolean(settingValue);
	}

	if (settingName.equalsIgnoreCase("sort")) {
		sort = toBoolean(settingValue);
	}

	if(settingName.equalsIgnoreCase("anyAudioFiles")) {
		anyAudioFiles = toBoolean(settingValue);
	}

	if(settingName.equalsIgnoreCase("pitchMode")) {
		pitchMode = toBoolean(settingValue);
	}

	if(settingName.equalsIgnoreCase("hardSwap")) {
		hardSwap = toBoolean(settingValue);
	}

	if(settingName.equalsIgnoreCase("noteRange")) {
		noteRange = settingValue.toInt();
		if(noteRange < 1) noteRange = 1;
		if(noteRange > 72) noteRange = 72;
	}

	if(settingName.equalsIgnoreCase("rootNote")) {
		rootNote = settingValue.toInt();
		if(rootNote < lowNote) rootNote = lowNote;
		if(rootNote > 96) rootNote = 96;
	}

	if(settingName.equalsIgnoreCase("loopMode")) {
		loopMode = settingValue.toInt();
	}
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

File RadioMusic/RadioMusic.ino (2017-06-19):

/*
 RADIO MUSIC
 https://github.com/TomWhitwell/RadioMusic
 
 Audio out: Onboard DAC, teensy3.1 pin A14/DAC
 
 Bank Button: 2
 Bank LEDs 3,4,5,6
 Reset Button: 8  
 Reset LED 11 
 Reset CV input: 9 
 Channel Pot: A9 
 Channel CV: A8 // check 
 Time Pot: A7 
 Time CV: A6 // check 
 SD Card Connections: 
 SCLK 14
 MISO 12
 MOSI 7 
 SS   10 
 
 NB: Compile using modified versions of: 
 SD.cpp (found in the main Arduino package) 
 play_sd_raw.cpp  - In Teensy Audio Library 
 play_sc_raw.h    - In Teensy Audio Library 
 
 from:https://github.com/TomWhitwell/RadioMusic/tree/master/Collateral/Edited%20teensy%20files

 Additions and changes:
 2016 by Jouni Stenroos - jouni.stenroos@iki.fi 
 - New bank change mode
 - Removing 330 file limit
 - Improving reset
 - File sorting
 - Audio crossfade
 - Some refactoring and organization of code.
 
 */
#include <EEPROM.h>
#include <SPI.h>
#include <SD.h>
#include <Wire.h>
#include "RadioMusic.h"
#include "AudioSystemHelpers.h"
#include "Settings.h"
#include "LedControl.h"
#include "FileScanner.h"
#include "AudioEngine.h"
#include "Interface.h"
#include "PlayState.h"

#ifdef DEBUG
#define D(x) x
#else
#define D(x)
#endif

// Press reset button to reboot
//#define RESET_TO_REBOOT
//#define ENGINE_TEST

#define EEPROM_BANK_SAVE_ADDRESS 0

#define FLASHTIME 	10  	// How long do LEDs flash for?
#define SHOWFREQ 	250 	// how many millis between serial Debug updates

#define peakFPS 30   //  FRAMERATE FOR PEAK METER

#define SD_CARD_CHECK_DELAY 20

// //////////
// TIMERS
// //////////

elapsedMillis showDisplay;
elapsedMillis resetLedTimer = 0;
elapsedMillis ledFlashTimer = 0;

elapsedMillis meterDisplayDelayTimer; // Counter to hide MeterDisplay after bank change
elapsedMillis peakDisplayTimer; // COUNTER FOR PEAK METER FRAMERATE


int prevBankTimer = 0;
boolean flashLeds = false;
boolean bankChangeMode = false;
File settingsFile;

Settings settings("SETTINGS.TXT");
LedControl ledControl;
FileScanner fileScanner;
AudioEngine audioEngine;
Interface interface;
PlayState playState;

int NO_FILES = 0;
uint8_t noFilesLedIndex = 0;

uint8_t rebootCounter = 0;

void setup() {

#ifdef DEBUG_STARTUP
	while( !Serial );
	Serial.println("Starting");
#endif // DEBUG_STARTUP

	ledControl.init();
	ledControl.single(playState.bank);

	// SD CARD SETTINGS FOR AUDIO SHIELD
	SPI.setMOSI(7);
	SPI.setSCK(14);

	boolean hasSD = openSDCard();
	if(!hasSD) {
		Serial.println("Rebooting");
		reBoot(0);
	}

	settings.init(hasSD);

	File root = SD.open("/");
	fileScanner.scan(&root, settings);

	getSavedBankPosition();

	audioEngine.init(settings);

	int numFiles = 0;
	for(int i=0;i<=fileScanner.lastBankIndex;i++) {
		numFiles += fileScanner.numFilesInBank[i];
	}
	D(Serial.print("File Count ");Serial.println(numFiles););

	if(numFiles == 0) {
		NO_FILES = 1;
		D(Serial.println("No files"););
		ledFlashTimer = 0;
	} else if(fileScanner.numFilesInBank[playState.bank] == 0) {
		D(Serial.println("Empty bank"););
		while(fileScanner.numFilesInBank[playState.bank] == 0) {
			playState.bank++;
			if(playState.bank == fileScanner.lastBankIndex) {
				playState.bank = 0;
			}
		}
		D(Serial.print("Set bank to ");Serial.println(playState.bank););
	}

	interface.init(fileScanner.fileInfos[playState.bank][0].size, fileScanner.numFilesInBank[playState.bank], settings, &playState);

	D(Serial.println("--READY--"););
}

void getSavedBankPosition() {
	// CHECK  FOR SAVED BANK POSITION
	int a = 0;
	a = EEPROM.read(EEPROM_BANK_SAVE_ADDRESS);
	if (a >= 0 && a <= fileScanner.lastBankIndex) {
		D(
			Serial.print("Using bank from EEPROM ");
			Serial.print(a);
			Serial.print(" . Active banks ");
			Serial.println(fileScanner.lastBankIndex);

		);
		playState.bank = a;
		playState.channelChanged = true;
	} else {
		EEPROM.write(EEPROM_BANK_SAVE_ADDRESS, 0);
	};
}

boolean openSDCard() {
	if (!(SD.begin(SS))) {

		Serial.println("No SD.");
		while (!(SD.begin(SS))) {
			ledControl.single(15);
			delay(SD_CARD_CHECK_DELAY);
			ledControl.single(rebootCounter % 4);
			delay(SD_CARD_CHECK_DELAY);
			rebootCounter++;
			Serial.print("Crash Countdown ");
			Serial.println(rebootCounter);
			if (rebootCounter > 4) {
				return false;
			}
		}
	}
	return true;
}

void loop() {

	#ifdef CHECK_CPU
	checkCPU();
//	audioEngine.measure();
	#endif

	if(NO_FILES) {
		// TODO : Flash the lights to show there are no files
		if(ledFlashTimer > 100) {
			ledControl.single(noFilesLedIndex);
			noFilesLedIndex++;
			noFilesLedIndex %= 4;
			ledFlashTimer = 0;
			rebootCounter ++;
			// Wait 3 seconds and reboot
			if(rebootCounter == 30) {
				reBoot(0);
			}
		}
		return;
	}

	updateInterfaceAndDisplay();

	audioEngine.update();

	if(audioEngine.error) {
		// Too many read errors, reboot
		Serial.println("Audio Engine errors. Reboot");
		reBoot(0);
	}

	if (playState.channelChanged) {
		D(
		Serial.print("RM: Going to next channel : ");
		if(playState.channelChanged) Serial.print("RM: Channel Changed. ");
		Serial.println("");
		);

		playState.currentChannel = playState.nextChannel;

		AudioFileInfo* currentFileInfo = &fileScanner.fileInfos[playState.bank][playState.nextChannel];

		audioEngine.changeTo(currentFileInfo, interface.start);
		playState.channelChanged = false;

		resetLedTimer = 0;

	}

}

void updateInterfaceAndDisplay() {

	uint16_t changes = checkInterface();
	updateDisplay(changes);
}

void updateDisplay(uint16_t changes) {
	if (showDisplay > SHOWFREQ) {
		showDisplay = 0;
	}
	if (bankChangeMode) {
		ledControl.showReset(1);// Reset led is on continuously when in bank change mode..
		if(!flashLeds) {
			ledControl.multi(playState.bank);
		}

	} else {
		ledControl.showReset(resetLedTimer < FLASHTIME); // flash reset LED
	}

	if (flashLeds) {
		if (ledFlashTimer < FLASHTIME * 4) {
			ledControl.multi(0x0F);
		} else if(ledFlashTimer < FLASHTIME * 8) {
			ledControl.multi(0);
		} else {
			ledFlashTimer = 0;
		}
	} else if (settings.showMeter && !bankChangeMode) {
		peakMeter();
	}
}

// INTERFACE //
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

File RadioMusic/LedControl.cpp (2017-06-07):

#include "Arduino.h"
#include "LedControl.h"

LedControl::LedControl() {

}

void LedControl::init() {
	pinMode(RESET_LED, OUTPUT);
    pinMode(LED0,OUTPUT);
    pinMode(LED1,OUTPUT);
    pinMode(LED2,OUTPUT);
    pinMode(LED3,OUTPUT);
}

// Set any combination of top row LEDS from the bottom 4 bits
// bit position is the opposite of light position
// e.g. if bottom 4 bits are 0001 the LEDs are * O O O
void LedControl::multi(uint8_t bits) {
    digitalWrite(LED3, HIGH && (bits & 1));
    digitalWrite(LED2, HIGH && (bits & 2));
    digitalWrite(LED1, HIGH && (bits & 4));
    digitalWrite(LED0, HIGH && (bits & 8));
}

// Set a single LED on the top row, others will be unlit
void LedControl::single(int index) {
    digitalWrite(LED3, HIGH && (index==0));
    digitalWrite(LED2, HIGH && (index==1));
    digitalWrite(LED1, HIGH && (index==2));
    digitalWrite(LED0, HIGH && (index==3));
}

void LedControl::showReset(boolean high) {
    digitalWrite(RESET_LED, high ? HIGH : LOW);
}

void LedControl::flash() {
    flashingBank = true;
    bankFlashTimer = 0;
}

// Set the bank and top row index.
// Different banks have different flashing rates
// Only supports 3 banks for now
void LedControl::bankAndSingle(int bank, int index) {
    // Flash waveform LEDs for custom waves
    if(bank > 0 && bank < 3) {
        if(bankFlashTimer >= bankLedFlashTimes[bank]) {
            bankFlashTimer = 0;
            flashingBank = !flashingBank;
            if(flashingBank) {
                single(index % 4);
            } else {
                single(15);
            }
        }
    } else {
    	single(index % 4);
    }
}

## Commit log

2014-10-13 Empty framework successfully plays file
2014-10-14 Add Hardware folder & Working CV & Pots
    [RadioMusic.brd, RadioMusic.sch]
2014-10-15 Added Bank switch + LEDs
2014-10-15 Output circuitry
    [RadioMusic.brd, RadioMusic.sch]
2014-10-15 Prep for time CV / Time Pot / Reset
    [RadioMusic.ino]
2014-10-16 Reset Switch
2014-10-16 Added crude pitch pot
2014-10-16 Basic hardware schematic complete
    Only needs SD connections & checking
    [RadioMusic.brd, RadioMusic.sch]
2014-10-17 Starting PCB layout
    [RadioMusic.brd, RadioMusic.sch]
2014-10-17 Added collateral folder
    Replace these files in the Teensy Audio Library
    [RadioMusic.brd, RadioMusic.sch]
2014-10-17 Untested fade circuit + more PCB layout
    [RadioMusic.brd, RadioMusic.sch]
2014-10-17 Power to op amps!
    [RadioMusic.brd, RadioMusic.sch]
2014-10-18 split signals across back and front
    [RadioMusic.brd, RadioMusic.sch]
2014-10-18 Simple Crossfading
    [RadioMusic.brd, RadioMusic.sch]
2014-10-18 First autorouted board
    [RadioMusic.brd, RadioMusic.sch]
2014-10-19 Add output level trim
    [RadioMusic.brd, RadioMusic.sch]
2014-10-19 Add reset LED
    [RadioMusic.brd, RadioMusic.sch]
2014-10-19 Add bank change to reset button
    [RadioMusic.sch]
2014-10-19 Separate Reset CV and Reset Button
    [RadioMusic.sch]
2014-10-20 Renumber Parts
    [RadioMusic.brd, RadioMusic.sch]
2014-10-20 Split Boards
    [RadioMusic_B.brd, RadioMusic_B.sch, RadioMusic_F.brd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]
2014-10-20 Back board reworking
    [RadioMusic_B.brd, RadioMusic_B.sch]
2014-10-20 Front board reworking
    [RadioMusic_F.brd, RadioMusic_F.sch]
2014-10-20 Routed boards for checking
    [RadioMusic_B.brd, RadioMusic_F.brd, RadioMusic_F.sch]
2014-10-21 Create panel PCB, fix position CV socket position
    [RadioMusic_F.brd, RadioMusic_Panel.brd, RadioMusic_Panel.sch]
2014-10-21 Panel design
    [RadioMusic_Panel.brd, RadioMusic_Panel.sch]
2014-10-21 Artwork on panels, notes on PCBs
    [RadioMusic_B.brd, RadioMusic_F.brd, RadioMusic_F.sch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]
2014-10-22 PCB cosmetic changes
    [RadioMusic_B.brd, RadioMusic_B.sch, RadioMusic_F.sch]
2014-10-23 Text subbing
    [RadioMusic_B.brd, RadioMusic_F.brd, RadioMusic_F.sch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]
2014-10-23 Gerbers sent to Seeed 23-10-14
    [RadioMusic.brd, RadioMusic.sch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]
2014-10-23 Moved .txt drill files
2014-11-04 Add value to trimmer
    [RadioMusic_B.brd, RadioMusic_B.sch]
2014-11-07 Fixed issues on Rev1 proto boards
    Diodes changed to BAT42
    LED resistors changed to 2k
    Ground error on Front board fixed
    [RadioMusic_B.brd, RadioMusic_B.sch, RadioMusic_F.brd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]
2014-11-07 Corrected power regulator label
    [RadioMusic_B.brd, RadioMusic_B.sch]
2014-11-07 Added BOM spreadsheet
    [RadioMusic_bom.xlsx]
2014-11-09 BOM update
    [RadioMusic_bom.xlsx]
2014-11-13 Swap channel IDs Fixes #10
    [RadioMusic.ino]
2014-11-13 Change map function in channel select Fixes #3
    [RadioMusic.ino]
2014-11-13 Add debug mode Fixes #22
    [RadioMusic.ino]
2014-11-13 Create ACTIVE_BANKS variable Fixes #1
    [RadioMusic.ino]
2014-11-13 Reenable EEprom save Fixes #2
    [RadioMusic.ino]
2014-11-13 Improve looping at end of files Fixes #27
    [RadioMusic.ino]
2014-11-14 Change mapping on Tune pot Fixes #28
    [RadioMusic.ino]
2014-11-15 Makes fading switchable Fixes #31
    [RadioMusic.ino]
2014-11-18 Timing and averaging changes to Start function
    Fixes #26
    [RadioMusic.ino]
2014-11-20 Hotswapping system
    Resets on SD read failure Fixes #5
    [RadioMusic.ino]
2014-11-27 Remove SD Card Bank saving code (didn't work)
    [RadioMusic.ino]
2014-11-28 Rewritten checkInterface() function
    Fixes #34
    [Helpers.ino, Interface.ino, RadioMusic.ino]
2014-12-01 Reorganise Gerbers
    [RadioMusic_B.GBL, RadioMusic_B.GBO, RadioMusic_B.GBP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]
2014-12-01 Change resistor values to reduce CV noise
    Fixes #13
    [RadioMusic_F.brd, RadioMusic_F.sch]
2014-12-01 Fix SD Card pin position
    Pin holes were 0.5mm off Fixes #14
    [RadioMusic_F.brd, RadioMusic_F.sch]
2014-12-02 Fix Voltage Regulator + cosmetics rear PCB
    Fixes #25
    [RadioMusic_B.brd, RadioMusic_B.sch]
2014-12-02 Front PCB Cosmetics
    [RadioMusic_F.brd]
2014-12-03 Front panel cosmetic fixes
    Fixes #19
    Fixes #18
    Fixes #17
    [RadioMusic_Panel.brd]
2014-12-03 Gerber Folder Changes
    [RadioMusic_B.GBL, RadioMusic_B.GBO, RadioMusic_B.GBP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]
2014-12-03 Rev2 Gerber Files
    Fixes #36
    [RadioMusic_B Rev2.brd, RadioMusic_B Rev2.sch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]
2014-12-03 Updated Gerber Readme
2014-12-07 Fix to glitching sound (not tested)
    Fixes #37
    [Helpers.ino, Interface.ino]
2014-12-07 Better fix for bank change glitches
    [Interface.ino]
2014-12-09 Fix Button colour on Eagle Schematic
    [RadioMusic_F.sch]
2014-12-09 Upload Schematic PDFs
2015-01-11 Restore wire library
2015-01-18 Fixed error in Module Test code
    Caused LED 3 and 4 to light from Tune CV input, and Start CV not to
    light an LED
    [ModuleTest.ino]
2015-02-04 Now reset by RISING interrupt on pin 9
    Faster and more reliable than polling with debounce.
    [Helpers.ino, Interface.ino, RadioMusic.ino]
2015-02-04 Comments and tidying of interrupt CV reset
    [Interface.ino, RadioMusic.ino]
2015-02-08 Add readme for edited Teensy files
2015-02-19 Enlarge pin holes for button
    [RadioMusic_F.brd, RadioMusic_F.sch]
2015-02-19 Readme for Gerbers
2015-02-25 Update silkscreen revision fixes #59
    Changed revision to rev 2.1
    Rev 1 = prototype
    Rev 1 with curved traces = actually rev 2 with resistor fix
    Rev 2.1 = updated silkscreen + bigger holes for button
    [RadioMusic_F.brd]
2015-03-03 Refactored Checkinterface()
    Fixes #55
    Fixes #49
    Fixes #63
    Fixes #51
    [Helpers.ino, Interface.ino, RadioMusic.ino]
2015-03-03 Upload rev 2.1 Gerber files
    [RadioMusic_F.GBL, RadioMusic_F.GBO, RadioMusic_F.GBP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]
2015-03-03 folder error
    [RadioMusic_F.GBL, RadioMusic_F.GBO, RadioMusic_F.GBP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]
2015-03-03 Rev 2-1 Eagle archive
    [RadioMusic_F rev2-1.brd, RadioMusic_F rev2-1.sch]
2015-05-13 Add resistor pic
2015-09-06 Update Eagle version
    [RadioMusic_F.sch]
2016-03-23 Fixed hotswap, file limit, reset and added sort.
    [Helpers.ino, Interface.ino, RadioMusic.ino]
2016-03-25 Reverted back to original timHyst handling, changed the zero snap code instead.
    [Interface.ino]
2016-08-14 Add Teensy versions
2016-10-20 added extra build image showing button orientation
2017-04-23 Windows doesnt like spaces on the end of directory names
    [RadioMusic_B Rev2.brd, RadioMusic_B Rev2.sch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]
2017-04-23 Edited teensy files not required.
2017-05-14 fix glitch when changing samples
    [AudioEngine.cpp, SDPlayPCM.cpp, SDPlayPCM.h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]
2017-05-15 Buffer fill bug. Check for empty bank selection from EEPROM and use non-empty bank.
    [AudioEngine.cpp, RadioMusic.ino, SDPlayPCM.cpp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]
2017-05-15 In pitch mode always reset to start with trigger / button.
    [RadioMusic.ino]
2017-05-16 Use state machine for reading settings to prevent infinite loop.
    [Settings.cpp]
2017-05-16 Increase buffer size to allow higher pitch shifts but limit shift range on high bandwidth samples.
2017-05-18 Fix 1 bank check
    [RadioMusic.ino]
2017-05-25 limit pitch shift when using 'anyAudioFiles'
2017-05-28 rootNote in settings. skip empty bank on bank change
    [RadioMusic.ino, SDPlayPCM.cpp, Settings.cpp]
2017-05-28 no crossfades in pitch mode
2017-05-29 Fix for stereo samples to read left channel only properly.
    [SDPlayPCM.cpp]
2017-06-07 reject files with unknown sample rates
2017-06-07 if no files are found flash the top leds and reboot after 3 seconds.
    [RadioMusic.ino, Settings.cpp]
2017-06-19 Use the right names for quantise options. Always flash reset LED when reset is triggered.
    [RadioMusic.ino, Settings.cpp]

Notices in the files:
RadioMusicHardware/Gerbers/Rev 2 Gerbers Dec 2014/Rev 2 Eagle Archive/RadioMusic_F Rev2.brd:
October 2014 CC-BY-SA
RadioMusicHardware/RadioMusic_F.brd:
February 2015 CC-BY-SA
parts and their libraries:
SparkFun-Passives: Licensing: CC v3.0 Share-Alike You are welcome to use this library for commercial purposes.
